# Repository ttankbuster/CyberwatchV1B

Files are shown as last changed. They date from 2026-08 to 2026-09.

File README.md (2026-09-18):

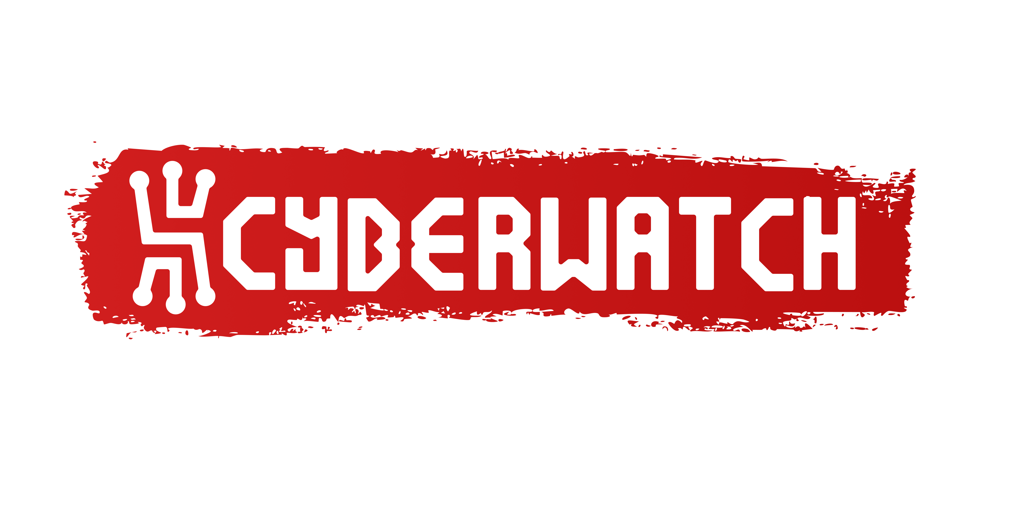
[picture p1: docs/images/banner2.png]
banner2
 
# CyberwatchV1B
The Cyberwatch is an extensible smartwatch built from scratch, targeting ESP32 hardware. It's current version is V1B.
Cyberwatch runs **Cyan**, a small operating system written in C with an embedded Lua runtime for app handling. Cyan is platform agnostic and can run on the watch and as a native desktop application, so the interface can be developed faster, without hardware in the loop by utilising [Clay](<https://github.com/nicbarker/clay>), a lightweight single header UI layout library. Apps are loaded at runtime from an SD card. 
Clay produces layout commands that are
consumed by either an ST7789V2 display handler on hardware or by SDL on a desktop machine. 
Cyan exposes hardware through a service architecture - a registry of
capabilities that apps and core tabs request as needed and can poll availability of arbitrarily. More info can be found with the [Word doc](<docs\Cyberwatch.docx>).

### Major Features
- Lua App Handling
- Watch-face
- Timer
- Stopwatch
- Remote Shell
- Settings

### Instillation
use `git clone --recurse-submodules https://github.com/ttankbuster/CyberwatchV1B.git` for installation, this git-repo uses submodules.

## Contents

## Functionality
| | |
| --- | --- |
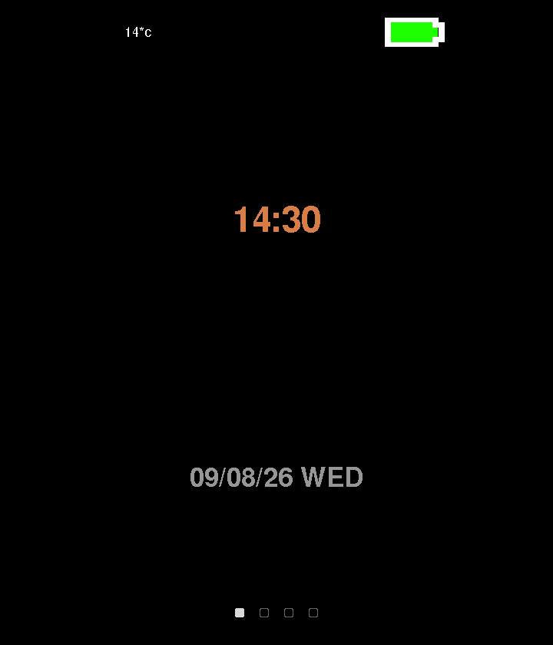
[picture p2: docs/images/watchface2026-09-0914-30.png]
Watch face
|  | **Watch face** - has digital and analogue variants. The analogue hands are drawn as quads on the same surface primitive used by apps. Shows the time, day of the week and date. |
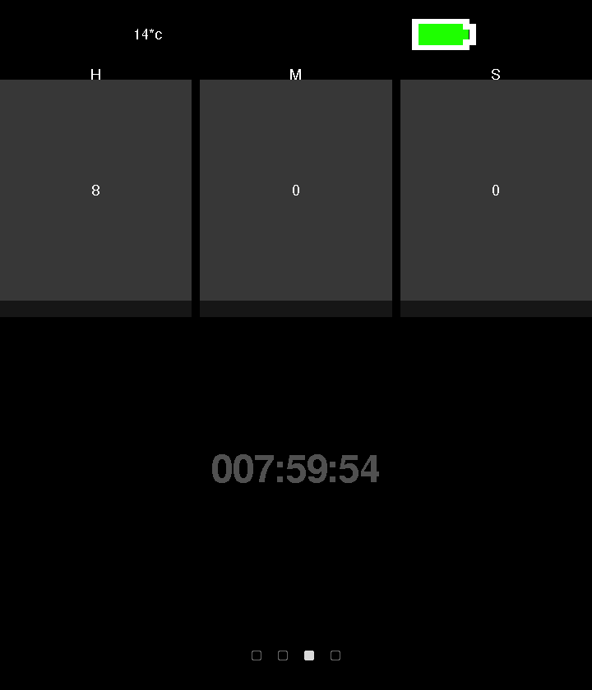
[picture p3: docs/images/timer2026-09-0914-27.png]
Timer
|  | **Timer** - three spin boxes for hours, minutes and seconds. Button 2 moves between fields, the crown adjusts the value, pressing the crown starts and pauses the timer. |
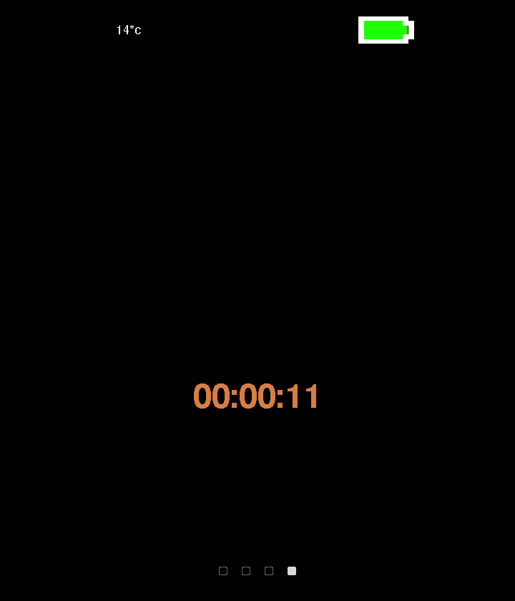
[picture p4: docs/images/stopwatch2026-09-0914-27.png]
Stopwatch
|   | **Stopwatch** - same interaction model, counting up rather than down. |
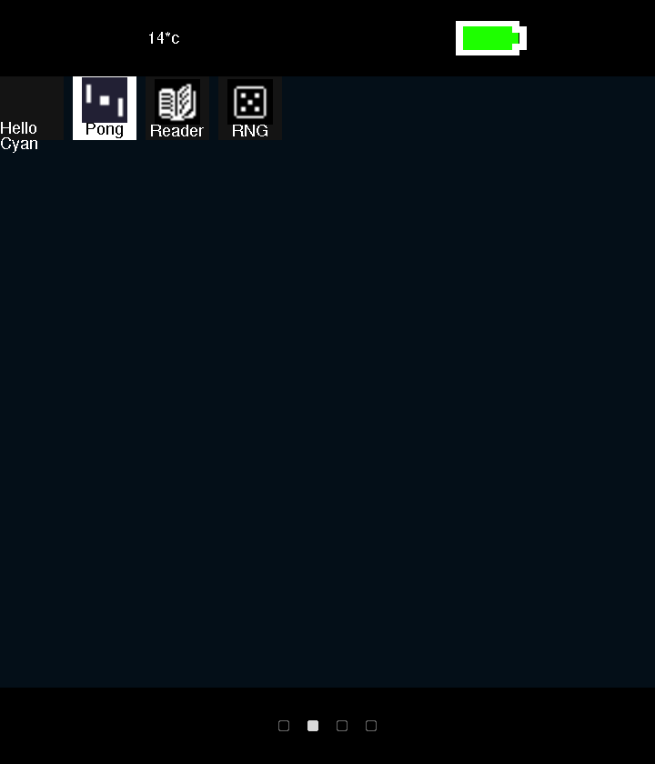
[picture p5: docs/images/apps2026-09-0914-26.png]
Catalogue
|  | **App catalogue** - displays a list of apps found on the SD card in rows and launches them. |
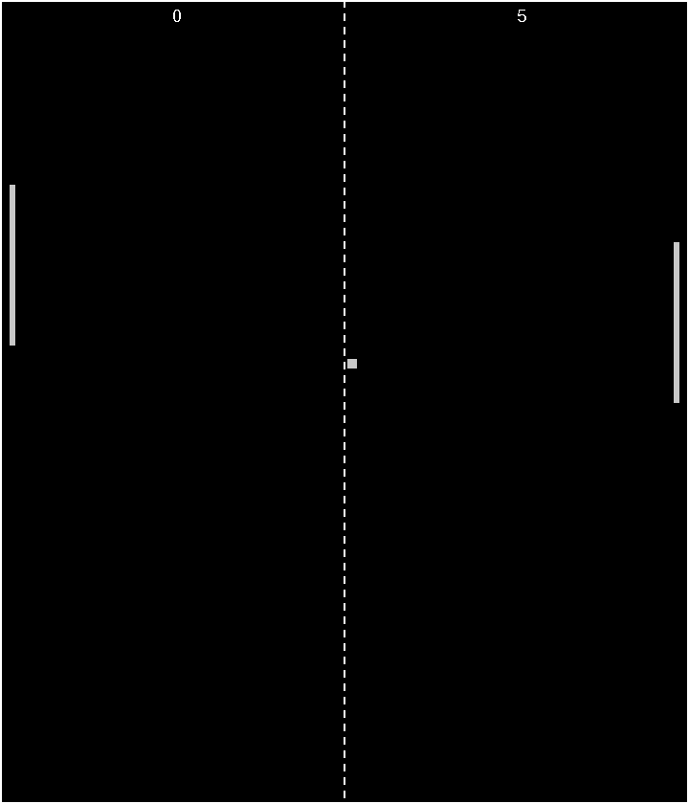
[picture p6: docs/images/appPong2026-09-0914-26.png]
Pong
|  | **Pong** - a demo app written entirely in Lua, using a bespoke app API. |
## Hardware
| | Function | Part | Interface | Notes |
| --- | --- | --- | --- | --- |
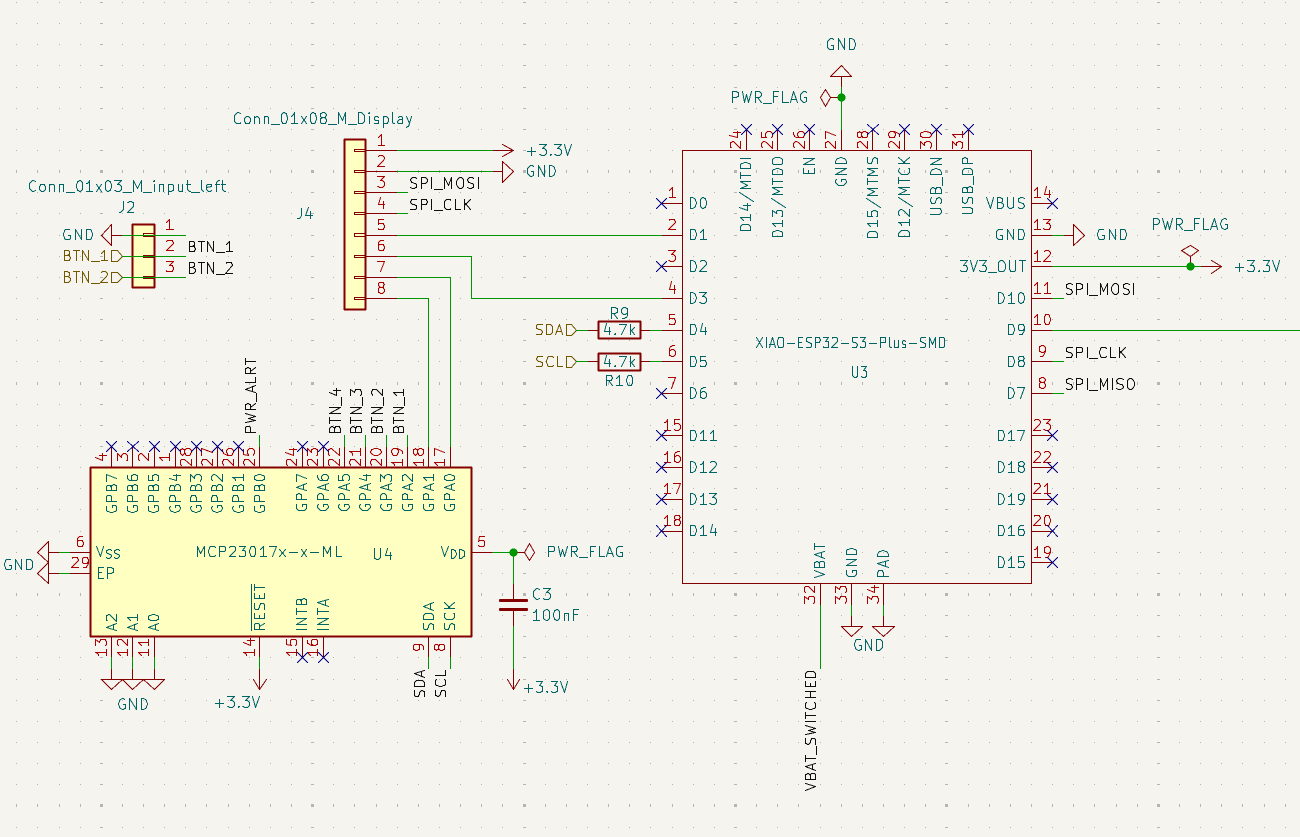
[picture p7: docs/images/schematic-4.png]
MCU
|  | MCU | Seeed XIAO ESP32-S3 Plus | --- | 240 MHz dual core, 8 MB PSRAM, 16 MB flash, WiFi + BLE 5.0, 14 µA deep sleep, integrated LiPo charging |
| Display  | Display | 1.69” LCD, ST7789V2 | SPI | - 240x280 pixel resolution<br>- 39x31.5mm |
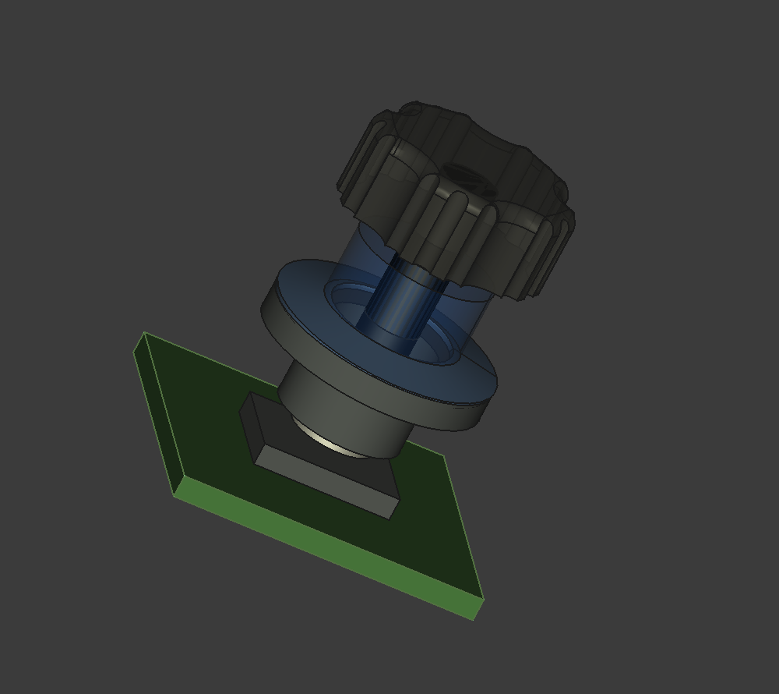
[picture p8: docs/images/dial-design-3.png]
Crown dial
|  | Crown dial | MT6701 magnetic encoder + dipole magnet. Annular Belleville popper for tactile feedback. | I2C | |
| GPIO expansion | GPIO expansion | MCP23017 | I2C | Frees ESP32 pins for the crown by moving the display RST and BL lines and the buttons onto the expander. |
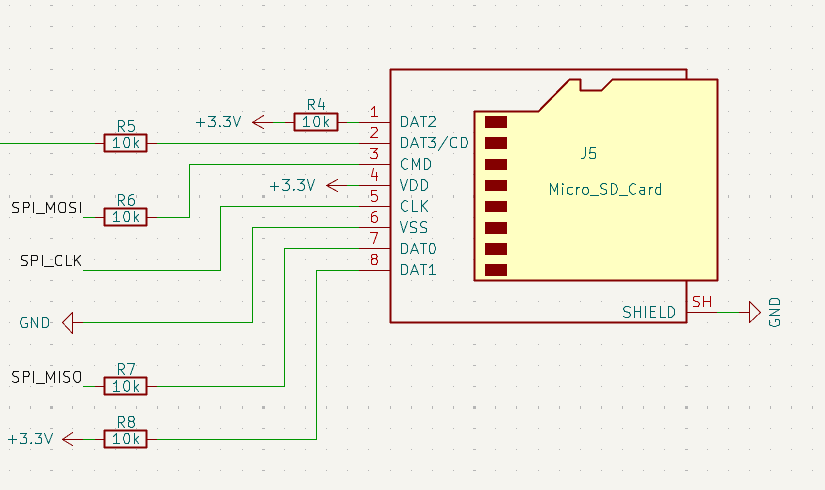
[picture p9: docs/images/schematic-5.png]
Storage
|  | Storage | MicroSD socket | SPI | 10 kΩ pull-ups on CS, MOSI, DAT1, DAT2 and MISO; <br>33 Ω series resistor on VCC to avoid the MCU browning out when the card is inserted |
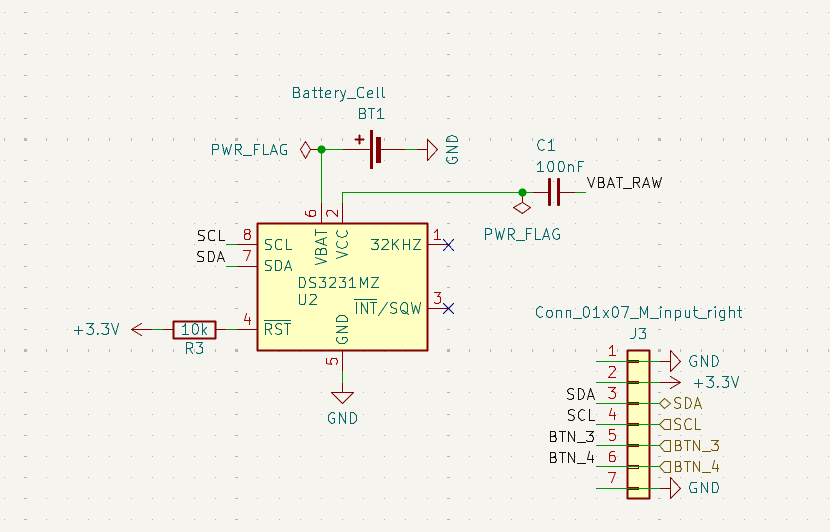
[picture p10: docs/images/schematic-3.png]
RTC
|  | Real-time clock & Temperature | DS3231MZ | I2C | Keeps time across power loss without a WiFi round trip.<br>Source of ambient temperature |
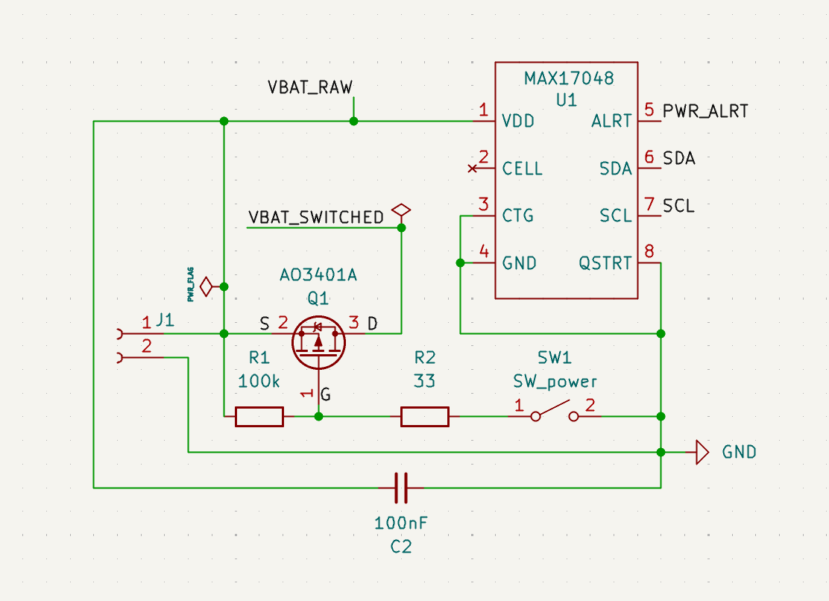
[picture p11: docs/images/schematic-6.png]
Battery gauge
|  | Battery gauge | MAX17048 | I2C | |
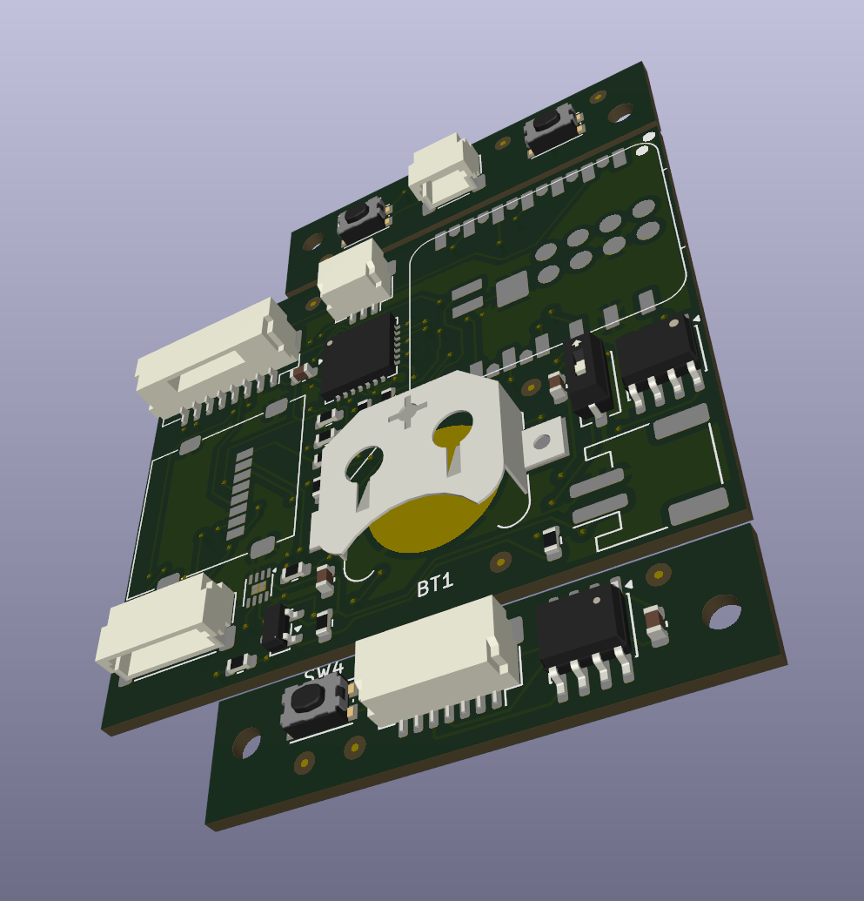
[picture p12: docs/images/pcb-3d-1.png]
Battery
|  | Battery | 3.7V 500mAh LiPo | --- | JST-PH Connector |
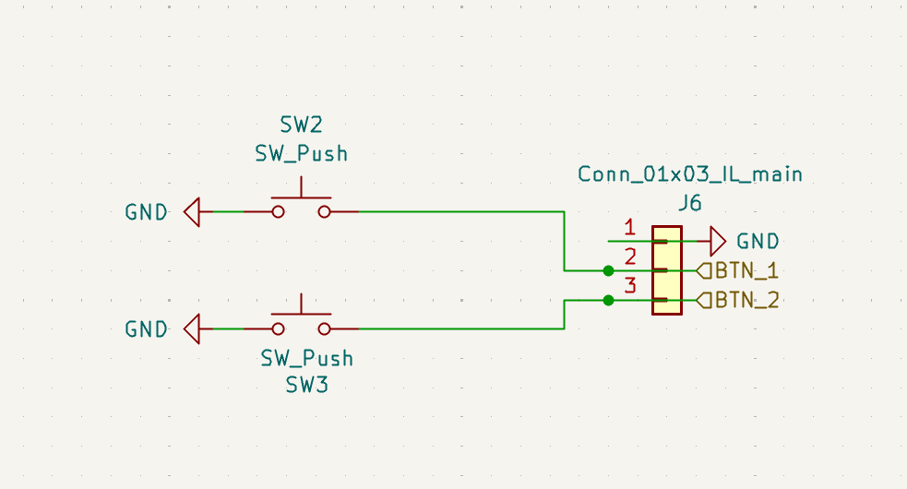
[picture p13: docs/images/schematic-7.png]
Buttons
|  | Buttons | 3x tactile switch | via MCP23017 | Buttons 1 and 2 on the left; button 4 and the crown on the right. |

## Software

The software follows a strict naming convention for all source code for the firmware and CyanOS to keep .

| For | Naming Convention |
| --- | --- |
| **types** | `PascalCase` |
| **fields** | `camelCase` |
| **functions** | `snake_case` |
| **constants** | `SCREAMING_SNAKE_CASE` |

`design/` holds the KiCad schematic and PCB, a FreeCAD case, component datasheets, and BOM spreadsheets for the hardware.

New public symbols should also take a `cyan_*` prefix. Styling is defined in `.clang-format` (stored at root).

Tests live under `test/`:
- `test/test_cyan_shell/` - Unity-style unit test for the shell command parser.
- `test/test_cyan_shell_repl/` - a Python-driven interactive REPL test, run via `pio test -e shell_repl`.

**PlatformIO Environments**

| Environment | Hardware Target | Notes |
| --- | --- | --- |
| `native` | Windows PC | uses SDL3 for window handling and rendering; this environment is used for development and iteration without hardware. |
| `esp32c3` | Seeed XIAO ESP32-C3 | earlier hardware target, watch-face tab only. |
| `esp32s3zero` | ESP32-S3 DevKitM-1 | full hardware target on a generic S3 dev board. |
| `xiao_esp32s3_plus`  | Seeed XIAO ESP32-S3 Plus  | full hardware target for the current CyberwatchV1B board. |
| `shell_repl` | Windows PC | dedicated env for interactively testing the shell command parser in isolation, run with `pio test -e shell_repl`. |

## Getting Started

Clone with submodules:
```
git clone --recurse-submodules https://github.com/ttankbuster/CyberwatchV1B.git
```
The repo vendors its dependencies (Clay, Lua, SDL3 + `_image`/`_ttf`, and two font families) as git submodules rather than package-manager dependencies, so `--recurse-submodules` is required - a plain clone leaves `external/` and the font folders empty.

To build and run the native simulator:
```
pio run -e native
build/native/program.exe
```
The native simulator has currently only been tested on Windows, where it should run out of the box with PlatformIO's toolchain and the SDL3 DLL installer written in python that checks for an instance of the SDL3 DLLs and coppies them into the executable directory if they are not found. This is to speed up starting on another machine. To target real hardware instead, swap `native` for one of the ESP32 environments above, e.g. `pio run -e xiao_esp32s3_plus -t upload`. This will flash to the ESP32-S3-Plus if it is connected with a usb-c cable, then start the operating system and serial monitor.

### Using the simulator

Launching the `native` build opens two windows: the watch display itself, and a separate console window for the interactive shell.

**Native CyanOS controls (`platform/pc/data_pc.c`)**

| Input | Maps to |
| --- | --- |
| Keys `1` / `2` / `3` / `4` | Buttons 1 / 2 / 3 / 4  |
| Mouse middle-click | Button 3 |
| Scroll wheel up/down | Crown dial up / down |
| up/down keys | Crown dial up / down |

**Shell commands (`cyan/console/cyan_shell.c`)**

| Command | Does |
| --- | --- |
| `help` | Lists all commands |
| `status` | Shows current Cyan status |
| `app list` / `launch <name>` / `exit` | Manage apps |
| `app permission add/remove/list <permission>` | Manage per-app permissions |
| `screenshot` | Saves a PNG of the current display to `screenshots/`, named by the active tab or running app plus a timestamp |
| `settings get/set/list <setting> [value]` | Read and write settings |

## Apps

Each app is a folder under `apps/` containing a `.cyan_app.lua` manifest plus its Lua script(s). Five example apps ship in the repo: `pong`, `reader`, `RNG`, `sodoku` and `hello_cyan`.

**Manifest fields (`.cyan_app.lua`)**

| Field | Meaning |
| --- | ---|
| `name` | Display name shown in the app catalogue |
| `script` | Entry-point Lua file, relative to the app's folder |
| `icon` | Icon bitmap shown in the catalogue |
| `dev` | If `true`, only loaded in debug builds |

Example (`apps/pong/.cyan_app.lua`):
```lua
return {
    name = "Pong",
    script = "pong.lua",
    icon = "icon.bmp",
    dev = false
}
```

Apps run sandboxed in their own Lua state and only see the API Cyan registers for them:
- `draw.rect(x, y, w, h, [r, g, b, a])` - filled rectangle
- `draw.text(x, y, text, [fontSize, r, g, b])` - text
- `draw.width()` / `draw.height()` - the app's drawable surface sizes
- `Event` - a table of input event constants (`Event.BUTTON1_DOWN`, `Event.SCROLL_UP`, etc.) for use in an app's event-handling code
- `print(...)` - routed into Cyan's own log output, tagged with the app's name

## Architecture

- **Service registry** (`cyan/data/services.h`) - a `ServiceRegistry` of `Service` entries (time, display, input, storage, power, apps, network, bluetooth, notifications, ...), each with `init`/`update`/`shutdown`/`available` functions and a criticality tier. Apps and core tabs can poll services at runtime.
- **Clay-based UI layer** (`cyan/clay_ui.c`) - an immediate-mode layout pass every frame, using [Clay](https://github.com/nicbarker/clay) to produce render commands consumed by a display backend.
- **`Surface` abstraction** (`cyan/data/surface.h`/`.c`) - a per-app pixel buffer that Lua apps draw into via the `draw` API, kept isolated from the OS's own rendering.
- **Platform backend split** - each platform implements its own `display_*` (rendering) and `data_*` (input/event) backends: `platform/pc/` (SDL3) and `platform/esp32/` (ST7789V2 over SPI via Arduino_GFX, MCP23017 I/O expansion).

The MCP23017 must finish initializing before the display's `RST` pulse, and the SD card's SPI setup must run after the display's own SPI init - reversing either hangs the board.

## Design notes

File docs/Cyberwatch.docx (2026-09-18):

# Cyberwatch V1B

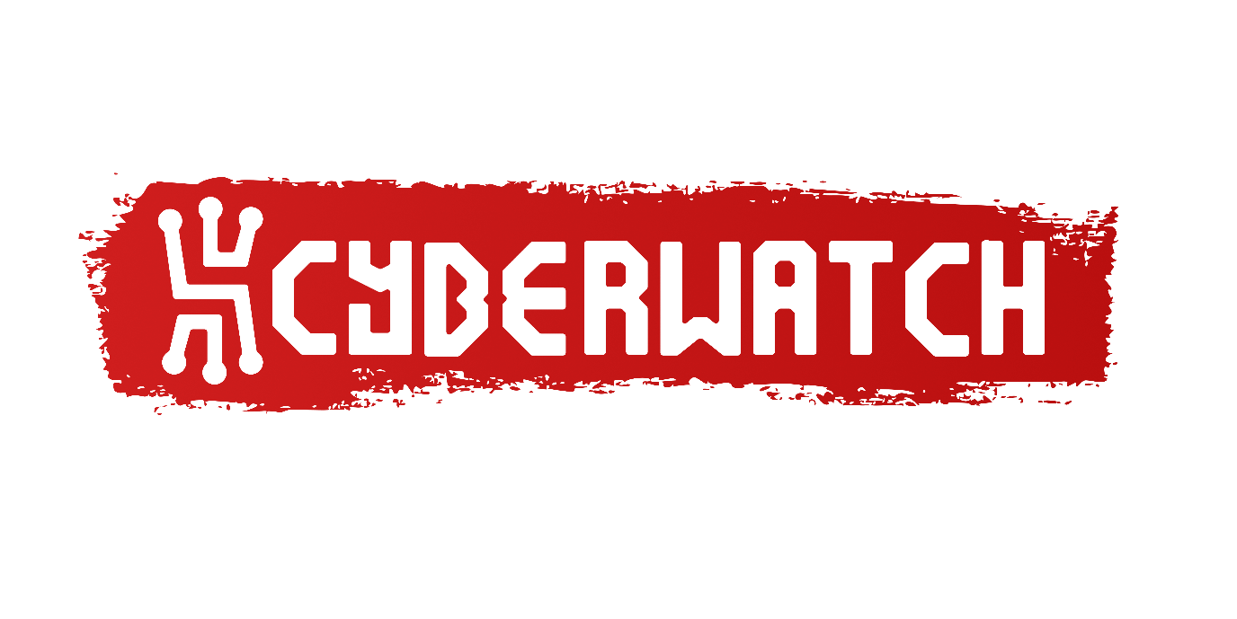
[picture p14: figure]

# 0.0 Introduction

Cyberwatch is a simple, versatile smartwatch with its own operating system called “Cyan”, for custom-made apps and tracking time. It is to a smartwatch what a “cyberdeck” is to a computer: open ended and reprogrammable.

A cyberdeck or cyber deck is a custom-built, portable personal computer, often one designed for a particular individualized purpose and usually with a cyberpunk (https://en.wikipedia.org/wiki/Cyberpunk) aesthetic.[1] (https://en.wikipedia.org/wiki/Cyberdeck) These devices are typically individually crafted, powered by laptop motherboards or single-board computers (https://en.wikipedia.org/wiki/Single-board_computer) (SBCs), such as Raspberry Pis (https://en.wikipedia.org/wiki/Raspberry_Pi), and include a display and keyboard

A coloured 1.69-inch LCD display shows the time, date and battery charge. The device is designed to operate for at least 24 hours on a single charge, and be recharged through a USB-C connection. A custom-built real time operating system called “Cyan” is responsible for managing hardware and the user interface. User interaction is facilitated by three physical buttons and a rotary crown, which can also be pressed as a button. The device measures x-mm by y-mm by z-mm. Cyberwatch began as an embedded systems project and a way to demonstrate my engineering ability. The longer-term ambition is more personal: to build a watch I genuinely want to wear, understand, repair and improve for as long as I am able. It is meant to work as a stand-alone device rather than an extension of a smartphone. It is not designed to track you or harvest your data. It is designed to be a useful tool, dependable and arguably more importantly: joyful.

Cyan is designed to target an ESP32 microcontroller, but is designed with platform abstraction in mind. This allows parts of the software to run on a PC for faster development and iteration, while the Cyberwatch hardware remains its primary platform for deployment.

## 0.1 Executive Summary

standalone one-page summary…

## 0.2 Index

# 1.0 Technical Overview

All requirements are assigned a reference number in the format of FR/NFR for Functional Requirement or Non Functional Requirement respectively, followed by a dash, then a category, then a number that is unique inside it’s given category.

Requirement Categories:

- A: User Interaction
- B: Display
- C: Application Handling
- D: System Management
- E: Platform Agnosticism

Change this to:

FR:

- A: Application Handling
- B: User Interaction
- C: System Management
- D: Display

NFR:

- P: Performance - rendering rate, input latency, response times
- W: Power & Endurance - battery life, charging, sleep current
- R: Reliability - graceful degradation, crash recovery, watchdog behaviour, app isolation
- M: Maintainability - platform abstraction, build separation, testability
- U: Usability - legibility at a glance, button feel, one-handed operation

## 1.1 Functional Requirements

Reference | Requirement Name | Description | Acceptance Criterion | Verification Method | Status
FR-A001 | Button Input | Cyberwatch shall accept input from three physical buttons.
FR-A002 | Rotary Input | Cyberwatch shall accept rotational input from the rotary crown.
FR-A003 | Crown Button | Cyberwatch shall detect presses of the rotary crown.
FR-B001 | Time Display | Cyberwatch shall display the current time.
FR-B002 | Date Display | Cyberwatch shall display the current date.
FR-B003 | Battery Status | Cyberwatch shall display the current battery charge level.
FR-B004 | Watch Face | Cyan shall provide a watch-face interface.
FR-B005 | Timer | Cyan shall provide a timer function.
FR-B006 | Stopwatch | Cyan shall provide a stopwatch function.
FR-C001 | Lua Applications | Cyan shall support applications written in Lua.
FR-C002 | Application Storage | Applications shall be stored on the hardware implementation’s SD card.
FR-C003 | Application Catalogue | Cyan shall provide an application catalogue from which installed applications can be selected.
FR-C004 | Application API | Cyan shall provide applications with access to supported display and input functionality.
FR-C005 | Application Manifest | Each application shall provide a manifest containing its required application information and services.
FR-D001 | Hardware Initialisation | Cyan shall initialise available hardware during system startup.
FR-D002 | Service Registration | Cyan shall identify available hardware capabilities and register the corresponding services.
FR-D003 | System Status | Cyan shall display the status of subsystems during startup.
FR-D004 | Reduced Capability Operation | Cyan shall continue operation with reduced capabilities when supported hardware or services are unavailable.
FR-E001 | PC Platform | Cyan shall be capable of operating on a PC platform for development and iteration.
FR-E002 | Platform Abstraction | Cyan shall separate platform-specific hardware implementations from platform-independent software functionality.

## 1.2 Non-Functional Requirements

…

## 1.3 System Architecture

layered model: hardware -> data/display -> service -> OS -> app

##Create a graphic here##

┌─────────────────────────────┐

│ Applications │ Lua, sandboxed, via App API

├─────────────────────────────┤

│ Cyan OS │ Shell UI, tabs, app lifecycle

├─────────────────────────────┤

│ Service Registry │ Time, Power, Input, Storage…

├─────────────────────────────┤

│ Hardware Abstraction │ Display, data, platform entry

├─────────────────────────────┤

│ Hardware │ ESP32-S3, ST7789, MCP23017…

└─────────────────────────────┘

Services are used to abstract across platform differences and provide a wrapper for the capabilities of the system which can be inspected during runtime. They may be only indirectly related to the underlying hardware, for example: notifications are purely a system capability, whereas storage may be unavailable if a component is missing or faulty – meaning .

Service | ID | Description | Criticality
Time | SERVICE_TIME | Provides current date and time from the platform RTC or system clock | HIGH
Power | SERVICE_POWER | Battery level, charge state, sleep and shutdown control | HIGH
Display | SERVICE_DISPLAY | Reports display dimensions to platform-independent code | HIGH
Input | SERVICE_INPUT | Polls physical buttons and rotary crown events | HIGH
Input Display | SERVICE_INPUT_DISPLAY | Pointer input for touchscreen or mouse | LOW
Storage | SERVICE_STORAGE | File read/write via the platform’s storage medium | HIGH
Network | SERVICE_NETWORK | WiFi connectivity and signal strength | MED
Bluetooth | SERVICE_BLUETOOTH | Bluetooth connection state | MED
Notifications | SERVICE_NOTIFICATIONS | Pending notification count from paired device | MED
Location | SERVICE_LOCATION | (reserved) | LOW
Audio | SERVICE_AUDIO | (reserved) | LOW
Vibration | SERVICE_VIBRATION | (reserved) | LOW

# 2.0 Hardware Design

…

## 2.1 Power System

…

## 2.2 Electronic Components

…

## 2.3 PCB Design

…

## 2.4 Structural Design

Enclosure/case etc…

2.5 Mechanical Design
- dial: bearing, magnet, tolerances

# 3.0 Software Design

…

## 3.1 Cyan

Cyan is the home-brewed operating system, custom built for the Cyberwatch hardware. On startup, Cyan will display a splash-screen and exhibit the Cyan logo.

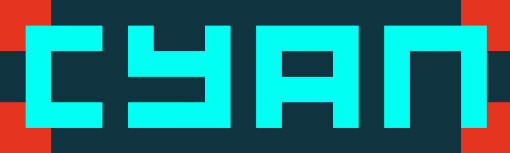
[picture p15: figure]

It will then load hardware capabilities and register services, checking the health of each system step by step. Cyan is designed to run with reduced capabilities, meaning it is robust against failure when hardware does not meet full expectations (see §1.3 System Architecture for details on Service handling). Displaying each sub-system’s status during boot. Once startup is complete, the user is taken to the watch-face - the first of four tabs Cyan provides: (1) Watch-face, (2) App Catalogue, (3) Timer, (4) Stopwatch. (elaborated on in §3.2 User Interface).

## 3.2 User Interface

A crucial library chosen for Cyan is Nic Barker’s Clay. A lightweight real time, and importantly, platform agnostic layout engine. The UI is first laid out using Clay and is then passed on to the renderer - which is implementation specific. During native targeting the rendering engine used is SDL3, whereas Arduino GFX supports hardware on the ESP32. The user interface is recalculated each updated, meaning it is event driven. This works well with Clay’s immediate mode architecture as recalculating the entire layout from scratch is very simple, but this can be slightly more intensive than persistent UI elements allowing the rendering loop to skip a portion of the screen altogether. Fortunately, immediate mode UIs also have the added benefit of robustness: because everything is recalculated from scratch each time, there are no miscalculations that can survive across frames. After layout calculations are complete, the list of render commands is interpreted by either the SDL3 Clay backend or a custom-built receptacle for ArduinoGFX, converting layout commands into draw commands.

Sometimes for avoiding complexity, Clay is bypassed as the primary mode of display-management. For example: during app execution…

### 3.2.1 Cyan Watch-Face Tab

The watch-face is a simple UI for showing the current time in a format of the user’s choice, stored as setting #xthe day of the week and current date, also configurable using settings #y and #z respectively.

This is achieved by storing a time object and character buffers which are written to each update.

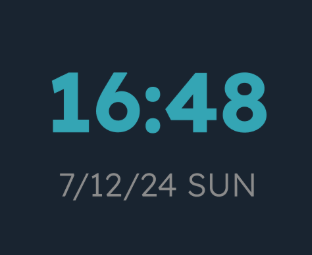
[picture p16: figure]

Allowing Cyan to retrieve the date and time from the current platform and produce a string which is then displayed on screen using Clay’s in-built String object.

### 3.2.2 Cyan App Catalogue Tab

…

### 3.2.3 Cyan Timer Tab

…

### 3.2.4 Cyan Stopwatch Tab

…

## 3.3 Application System

Cyan provides support for applications written in Lua. These applications, on the hardware implementation, are stored on the SD card, inside of the root folder “apps/”. Each app has its own folder, containing a Lua script, a thumbnail image and a manifest file also written in Lua – this allows for a simpler implementation than writing an additional interpreter for a JSON manifest. During startup, Cyan scans through all subdirectories inside of the apps/ folder and spins up a temporary Lua instance to read manifest files into an app object, storing information such as the name of the app, the file address to the app thumbnail and the services the app will require (e.g. WiFi).

Once an app has been selected to launch from the app catalogue, a new Lua instance is created to interpret the app’s script in real time. To exit an application, the user can press button one.

An API is exposed to the application, allowing draw calls and input events to be transacted between the operating system and a running application. All visuals produced by the application are rendered to a surface target abstraction, allowing the app to display inside of the pre-existing UI by converting the in-app coordinates to global screen coordinates after the layout step is completed.

API Draw Calls
Name | In App Signature | Backend Signature | Effect
Draw Rectangle | draw.rect (x, y, w, h, r, g, b) | AppHandler _draw_rect (lua_State *L) | Draws a rectangle using specified quad and colour.
Draw Text | draw.text (x, y, text, font_size, r, g, b) | AppHandler_draw_text (lua_State *L) | Prints text on screen at the given coordinate
Draw Width | | AppHandler _draw_rect (lua_State *L)
Draw Height

## 3.4 Hardware Abstraction

…

## 3.5 PC Platform

SDL etc

## 3.6 Settings & Configuration

- standalone, no Lua dependency

## 3.7 Remote Shell

- serial now, WiFi later

# 4.0 Testing and Verification

retrospective: hardware bring-up discipline

prospective: planned Unity tests

# 5.0 Development History

…

## 5.1 Hardware Decisions

MCU

- ESP32-S3 over C3 for primary target; C3 kept as reduced-capability build
- XIAO ESP32-S3 Plus over base S3 and Waveshare S3-Zero
- module, not bare IC (V1) - isolates RF risk to V2

DISPLAY

- Waveshare 1.69" ST7789V2, 240x280 SPI
- JST GH 1.25mm 8-pin - custom symbol built, no Plus-specific footprint found

I/O EXPANSION

- MCP23017 for I2C GPIO (buttons + display RST/BL)
- SOIC (-SO) over QFN (-ML) - hand-solderability

RTC

- DS3231 family - free built-in temp sensor
- DS3231MZ (SOIC-8) over DS3231M (SOIC-16) - same specs, smaller
- RV-3028-C7 rejected for V1 (leadless) - deferred to V2
- CR1220 over CR2032 - smaller, shorter but replaceable backup life
- no trickle-charge circuit - real fire-risk finding, deliberately omitted

ROTARY INPUT

- AS5600 (Hall-effect I2C) over mechanical encoder - sealed, contactless
- SOIC-8 footprint verified against real datasheet dims
- footprint sourced from KiCad's own library, not unverified SnapEDA
- MLX92213 rejected - wrong sensor category (binary latch, not angle)
- ADA4570BRZ rejected - needs external ADC, wrong complexity for use case
- bearing material - still open, deferred to empirical test

STORAGE

- bare microSD socket, not breakout module
- SPI mode over SDIO - fewer pins
- SCK/MOSI shared with display bus, each device own CS

POWER

- AO3401 P-MOSFET for isolation - raw switch undersized for WiFi burst current
- MAX17048 fuel gauge - simple, proven, official Espressif driver (MAX17055 deferred to V2 - more accurate, more complex)
- JST-PH 2.0mm 2-pin for main battery

PASSIVES

- I2C pull-ups: 4.7k, per AS5600 datasheet
- SD pull-ups: 10k, per Espressif ESP-IDF docs

## 5.2 Software Decisions

…

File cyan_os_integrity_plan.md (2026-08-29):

# Cyan OS Integrity Initiative — Stepped Plan

*Formalized plan for hardening Cyan OS: fault tolerance, service criticality,
a native settings system, power-aware rendering, and a remote shell — bounded
by a full audit on each end.*

---

## Cross-cutting rule, applies to every phase below

**Each phase ends with a full boot-and-smoke-test on real hardware before
the next phase begins, followed by a git tag at that known-good point.**
This project has already hit the same regression twice (`tabCount`
initialization silently disappearing during unrelated edits, reintroducing
a crash that was already fixed once). An 8-plus-phase restructuring effort
touching core architecture is exactly the environment that happens in
again, quietly, several phases deep, with no easy way to know which phase
introduced it. This rule is non-negotiable, not a nice-to-have.

---

## Current status (updated as work progresses)

- **Phase 1 closed, tagged `phase1-pc-verified`.** **Phase 2 (criticality
  model) started** — data model landed (`CyanCriticality` enum, the two
  `Service` fields, static tiers for the two currently-registered
  services), full detail under Phase 2 below.
- **Phase 0, audit pass complete, both confirmed bugs now fixed in the
  working tree.** Originally decided to keep Phase 0 audit-only and defer
  both bugs (the `app_handler.c` buffer overflow and the
  `display_st7789.cpp` out-of-bounds read) to Phase 1 alongside the
  rename — superseded: fixed directly instead, each as its own isolated
  change (see Audit Findings Log for the diffs). **Committed** as
  `de4f58a` ("memory safety fix"), which also included the
  `main_esp32.cpp` dead-code cleanup and this plan doc itself.
  **PC half of the boot-and-smoke-test complete**: native build compiles
  clean and the launched binary stays up and responsive (window "Watch",
  no crash) — confirms the `app_handler.c` fix. Tagged at that point:
  `phase0-pc-verified` → `de4f58a`. **Still outstanding**: the ESP32
  hardware boot test for the `display_st7789.cpp` icon-dimension fix,
  which is ESP32-only and unverifiable on the PC build. Phase 0 isn't
  fully closed until that runs too.
  - **Follow-up commit landed outside this documented flow**: `8e53165`
    ("memory safety fix #2") added three more `app_handler.c`/`.h` changes
    on top of `de4f58a` — see Audit Findings Log for detail on each.
    Reconciled here since it wasn't logged when made, matching the
    cross-cutting rule's concern about silent drift between phases.
    PC boot-and-smoke-test re-run against this commit specifically
    (native build clean, binary stayed alive and responsive, indexed all
    5 apps correctly, no crash) — tagged `phase0-pc-verified-2` →
    `8e53165`. ESP32 hardware boot test is still the one outstanding item
    blocking Phase 0 closure — unverifiable from this environment,
    needs to be run on real hardware.
  - **Explicit decision, 2026-08-16**: no ESP32 hardware access right
    now. Rather than stall, proceeding into Phase 1 with Phase 0 held
    open specifically on that one item — the PC-verifiable half (the
    `app_handler.c` overflow, and everything else audited off the
    source directly) is done and tagged. The ESP32 boot test for the
    `display_st7789.cpp` icon fix will be run once hardware is
    available again; this is a deliberate, logged exception to the
    cross-cutting rule's "boot-test before the next phase" ordering,
    not a silent skip.
  - `src/` reconciliation: **resolved** — confirmed directly against the
    repo tree that no `src/` directory exists; nothing to migrate.
  - Entry points audited (`main_pc.c`, `main_esp32.cpp`) — see Audit
    Findings Log below.
  - `cyan_os.c`/`cyan_os.h` audit: **unblocked and complete** — read
    directly off disk (`cyan/cyan_os.c`, `cyan/cyan_os.h`) once working
    from Claude Code, which has direct filesystem access; the prior
    attachment-delivery issue doesn't apply in this environment. Audit
    expanded outward from there to everything `cyan_os.c` pulls in
    directly: `app_handler.c/h`, `surface.c/h`, `services.h`,
    `services_base.c`, and both platform backends
    (`data_pc.c`/`display_sdl.c`, `data_esp32.cpp`/`display_st7789.cpp`) —
    see Audit Findings Log below. Two concrete, reproducible bugs found
    (buffer overflow, out-of-bounds read); both deferred to Phase 1, see
    decision above.
- **Decision made, deferred**: `CyberwatchData` → `CyanData` rename,
  agreed but intentionally not executed until Phase 1 (naming pass), so
  it happens as one deliberate sweep rather than piecemeal. Scope
  confirmed during this pass: touches `cyan_os.c`, `cyan_os.h`, `data.h`,
  `app_handler.h`, `services.h`, and every platform data file — matches
  what Phase 1 already expected, no surprises. **Done** — landed in
  `6d60554`.
- **Gap reconciled, 2026-08-29**: this status section hadn't been updated
  since `6d60554`, but 8 more commits had landed since (mostly unrelated
  hardware/case-design/documentation work — `485a9d7`, `b2f2483`,
  `c793bb0`'s electronics portion, and the schematic/analogue commits
  through `9153969`). One of those, **`c793bb0`, silently renamed every
  `app_handler_*` function to `AppHandler_*`** (PascalCase) without being
  logged anywhere — exactly the undocumented-drift scenario the
  cross-cutting rule exists to catch, since every other module
  (`services_*`, `surface_*`, `display_*`, `cyan_*`) stayed snake_case.
  Latest commit (`0ef6e52`, "added code style enforcement") also added
  `.clang-format` plus two **empty** stub files, `cyan/cyan_shell.c` and
  `cyan/cyan_shell.h` — read as early Phase 3 scaffolding, but Phase 2
  (criticality model) hasn't been started yet (confirmed: `services.h`
  has no `CyanCriticality` enum or `staticCriticality`/`dynamicCriticality`
  fields). **Explicit decision**: revert the `AppHandler_*` drift back to
  `app_handler_*`, finish Phase 1's two still-outstanding dead-code items
  before moving on, and leave the `cyan_shell.c/h` stubs untouched for
  now — Phase 2 comes next, per the plan's own sequencing.
  - Reverted in the working tree: `app_handler_init`, `app_handler_launch`,
    `app_handler_unload`, `app_handler_run_frame` (was renamed
    `AppHandler_update`), `app_handler_dispatch_events`,
    `app_handler_shutdown`, `app_handler_index`, `app_handler_print`, and
    the four Lua draw closures (`app_handler_draw_rect/width/height/text`,
    previously `lua_draw_*` before `c793bb0`, then `AppHandler_draw_*`) —
    all back to snake_case, across `app_handler.c`, `app_handler.h`, and
    every call site in `cyan_os.c`. See Audit Findings Log for detail.
  - Both remaining Phase 1 dead-code items (see Audit Findings Log,
    original entries) are now resolved: `cyan/data/timer_handling.c`
    deleted (empty, vestigial), `display_load_image()` in
    `display_st7789.cpp` deleted (dead, zero call sites, confirmed again
    before removal).
  - PC boot-and-smoke-test re-run against this working tree: native build
    clean, binary launched, stayed alive and responsive for 5+ seconds
    with no crash or error output, terminated cleanly. Tagged
    `phase1-pc-verified` once committed.
  - **New finding, not fixed this pass**: `cyan/tabs/screen_app.c` and
    `screen_catalogue.c` have their own pre-existing mixed-case names —
    `clay_AppHandler_app`, `clay_AppHandler_catalogue`,
    `render_AppHandler_catalogue`, `AppHandler_catalogue_move` — embedding
    `AppHandler` PascalCase inside otherwise snake_case names. These
    predate `c793bb0` (unrelated to that drift) and predate this plan's
    Phase 0 audit entirely. Left as-is — out of scope for this specific
    drift-revert — but logged as a Phase 1 naming-sweep candidate.

---

## Audit Findings Log

*Running log, appended to as each file is reviewed — not just Phase 0's
findings, every phase that touches existing code adds here.*

### `platform/pc/main_pc.c`, `platform/esp32/main_esp32.cpp`

| Finding | Severity | Disposition |
|---|---|---|
| ESP32 `loop()`'s `bool running` is declared fresh every call, value never meaningfully consulted afterward | Informational | **Accepted, known pattern** — ESP32's `loop()` has no real "exit" concept regardless. Recorded so a future reader doesn't mistake this for an oversight |
| Commented-out dead code (`// while(1)delay(1000);`) in `setup()` | Trivial | Cleanup item — sweep in Phase 1 |
| `main_pc.c` uses `clock()` for `dt` — measures CPU time, not strictly wall-clock; can diverge under some schedulers | Informational | Recorded as a known characteristic, matches original project convention — not changed unless later deliberately decided otherwise |
| Neither entry point has bounded-time protection around `esp32_hardware_init()`/`cyan_init()` failure — both halt forever or return an error | Expected, pre-Phase-4 | **Not a new finding** — this is exactly what Phase 4's bounded-time-init work replaces |

### `cyan/cyan_os.c`, `cyan/cyan_os.h`, and everything they directly pull in (`app_handler.c/h`, `surface.c/h`, `services.h`, `services_base.c`, `data_pc.c`/`display_sdl.c`, `data_esp32.cpp`/`display_st7789.cpp`)

| Finding | Severity | Disposition |
|---|---|---|
| `app_handler.c:184-185` (`app_handler_index`) — `snprintf(app.name, MAX_FILE_PATH, ...)` and `snprintf(app.path, MAX_FILE_PATH, ...)` passed `MAX_FILE_PATH` (256) as the size bound, but `app.name`/`app.path` are each `char[MAX_FILE_NAME]` (64 bytes) per the `AppEntry` struct (`app_handler.h:18-19`). For `app.path`, the written content is `"<path>/<foldername>"` — not bounded to ≤63 chars the way `folders.names[i]` alone is — so a folder name of roughly 60+ characters overflowed past `path`'s 64-byte field into the adjacent `icon` field. `app.name`'s copy was currently masked (safe only because `scan_folder` truncates source names to ≤63 chars first), but the size argument itself was still wrong. | **Bug — reachable stack buffer overflow** | **Fixed** — originally logged as deferred to Phase 1, but fixed immediately instead once flagged: both calls now use `sizeof(app.name)` / `sizeof(app.path)`. Still needs the boot-and-smoke-test before this is considered closed |
| `display_st7789.cpp:109` and `:114` — `convertRgb888ToRgb565(ICON_EMPTY_TAB, ICON_BATTERY_WIDTH, ICON_BATTERY_HEIGHT)` and the equivalent for `ICON_FULL_TAB` passed the **battery** icon's dimensions instead of their own. Confirmed against the actual asset headers: `ICON_BATTERY` is 30×18 (540px), `ICON_EMPTY_TAB`/`ICON_FULL_TAB` are each 12×12 (144px) — so this read ~396 pixels (1.5KB) past the end of a 144-pixel static array on every boot, and also left `iconEmptyTab.pixels`/`iconFullTab.pixels` populated with the wrong stride relative to `width`/`height` — garbled tab icons, independent of the OOB read. PC's `display_sdl.c:55-62` never had this bug. | **Bug — confirmed out-of-bounds read + wrong render** | **Fixed** — originally logged as deferred to Phase 1, but fixed immediately instead once flagged: both calls now use each icon's own `ICON_EMPTY_TAB_WIDTH/HEIGHT` / `ICON_FULL_TAB_WIDTH/HEIGHT` constants. ESP32-only change — needs the boot-and-smoke-test on real hardware before this is considered closed (can't be verified on the PC build) |
| `IconHandle`/`imageHandle` pattern — explicit audit target from the Phase 0 scope below | N/A | **Checked, consistent — no bug.** It's a deliberately opaque, per-platform `void*`: PC (`data_pc.c`/`display_sdl.c`) always writes/reads it as `SDL_Texture*`; ESP32 (`data_esp32.cpp`/`display_st7789.cpp`) always writes/reads it as `IconHandle*`. Platform-agnostic code (`screen_catalogue.c:72`) only passes it through to `display_draw_image`, never dereferences it directly. No cross-platform mixing found. |
| `cyan/data/timer_handling.c` is an empty file, despite its name implying it holds `timer_init`/`timer_cycle_element`/`timer_toggle`/`timer_spinbox_input` (declared in `data.h`). Traced and resolved: those are actually implemented in `cyan/tabs/screen_timer.c`, and `stopwatch_toggle`/`stopwatch_reset` in `cyan/tabs/screen_stopwatch.c`. | Trivial | **Not a missing-implementation bug** — vestigial/misleadingly-named empty file. **Deleted**, 2026-08-29 |
| `display_load_image()` in `display_st7789.cpp:166` is defined but has no call sites anywhere in the codebase and isn't declared in `display.h`. | Trivial | Dead code — **deleted**, 2026-08-29, re-confirmed zero call sites first |
| `app_handling/app_handler.c`, all six public functions (`app_handler_init/launch/unload/run_frame/dispatch_events/shutdown`) plus internal `app_handler_index` and the Lua-facing statics, were silently renamed to `AppHandler_*` (PascalCase) in `c793bb0`, undocumented at the time. | **Undocumented drift, matches the cross-cutting rule's exact concern** | **Reverted to snake_case**, 2026-08-29, per explicit decision — see Current status above for full list and reasoning |
| `cyan_os.h`'s include guard is `CYBERWATCH_H` (`cyan_os.h:2-3`) — leftover from the pre-rename name. Extends the Phase 1 naming-drift note (which already covers function naming) to include guards specifically. | Informational | Folds into the already-deferred `CyberwatchData` → `CyanData` sweep in Phase 1, not a new decision |
| Input debounce — confirmed at its exact location: `data_esp32.cpp:43-63` (`pollButtons`) does pure edge detection (`pressed != lastButtonNPressed`), no time-based debounce anywhere in the poll path. | Confirmed, matches Phase 0 scope | Not a new finding — this is the debounce gap the plan already named as an explicit audit target (see below); recorded here with its concrete file/line now that the file has been read directly |
| `app_handler.c:186` (`app_handler_index`, landed in `8e53165`) — even after the `sizeof(app.path)` fix, `snprintf` silently truncates rather than erroring when `"<path>/<foldername>"` still doesn't fit `app.path`'s 64 bytes. A truncated path is a distinct hazard from the original overflow: it's a valid-looking path to the *wrong* location (or a nonexistent one), which fails later, further from the actual cause. | Hardening, not a new memory-safety bug (the overflow itself was already fixed) | **Fixed** — `snprintf`'s return value is now checked; a folder name that would overflow `app.path` is logged and the entry is skipped instead of silently truncated. Covered by this pass's PC boot-and-smoke-test (`phase0-pc-verified-2`) |
| `app_handler.c:266` (`app_handler_run_frame`, landed in `8e53165`) — no null check on `AppHandler->appLua` before dereferencing it via `lua_getglobal`. Traced every call site (`cyan_os.c:117-189`): all four `data.state` writes (`launch_app`, `exit_app`, init, shutdown) update `state` and `appLua` together, synchronously, single-threaded — so a null-`appLua` call during `CYW_APP_RUNNING` isn't reachable through any currently-existing control path. | Defensive hardening, not a demonstrated live bug under current control flow | **Fixed** — added as a guard anyway (cheap, and Phase 6's capability-enforcement/Lua-bounds work will add more control paths here where this stops being trivially true). Worth re-checking reachability once Phase 6 lands |
| `app_handler.h` — `app_handler_count`, `app_handler_name`, `app_handler_icon`, `app_handler_is_running` were declared but never defined or called anywhere in `cyan/`. | Trivial | **Removed** in `8e53165`, ahead of the general Phase 1 dead-code sweep — confirmed zero remaining references before deletion |
| `platform_resolve_path()` — declared in `data.h`, defined separately on both `data_pc.c` (SDL_malloc-backed) and `data_esp32.cpp` (malloc-backed) — zero call sites anywhere in the codebase on either platform. Distinct from `platform_store_resolved_path()` (the caller-supplies-the-buffer variant), which *is* used everywhere and stays. | Trivial | Dead code, both platforms — **deleted**, 2026-08-29, from `data.h` and both platform `.c` files. PC build/boot-tested; ESP32 side is a pure deletion of an unreferenced function, same risk profile as the PC-verified half |

### `data_esp32.cpp` / `data_pc.c` vs. the services registry — architectural finding, 2026-08-29

Read `data_esp32.cpp` in full while starting Phase 2. **The services
registry that Phase 2's criticality model sits on top of is bypassed
entirely by every real subsystem except Time and Power, on both
platforms.** Concretely: ESP32's `pollButtons`/`pollEncoder` (Input),
`readRTC` (Time — note ESP32 doesn't even register a `TimeService`,
unlike PC), and `scan_folder`/`load_image` (Storage) are all called
directly from `update_data()`/`app_handler.c`, never through a
registered `InputService`/`StorageService`. PC's `data_pc.c` has the
identical shape: `scan_folder`/`load_image` (Storage) and display's own
event polling (Input) are wired directly, not through the registry.
`register_available_services` on ESP32 (`data_esp32.cpp:311-313`) is a
no-op that only logs. **This means `services_is_available()` would
report `Input`/`Storage`/`Display`/`Notifications` as unavailable on
both platforms today, even though Input and Storage plainly work** —
the registry just was never told about them.

This isn't a bug in what exists — everything that's wired directly
still functions correctly. It's a **gap between the architecture the
plan's later phases assume and what's actually built**: Phase 5
("periodic re-registration / availability re-check for every service")
and Phase 4's boot-ordering work both presuppose the registry is the
real source of truth for every subsystem, which isn't true yet. Left
unflagged, Phase 4/5 would either silently build on a registry that's
missing most of the OS, or rediscover this same gap mid-phase.

**Not fixed this pass** — deliberately. Registering Input/Storage/
Display/Notifications as real services means restructuring the main
update loop on both platforms, which is a materially bigger and riskier
change than this pass's scope (dead-code cleanup + a data-model addition).
Recorded here as a decision point for whichever phase migrates these —
most naturally Phase 2's own completion (finish what it started) or as
explicit prep work at the top of Phase 4, before boot-ordering logic
starts relying on registry state that isn't there yet.

**Before changing anything.**

- **Reconcile the actual current file tree against what's been assumed in
  prior planning.** Confirmed via direct repo check: `src/` still exists
  as a top-level folder alongside `cyan/`, contradicting the last project
  status summary's description of a full migration. Resolve this first —
  know what you're actually starting from.
- First audit pass, specifically for:
  - Memory safety (null-pointer risk, buffer bounds, the `IconHandle`
    pattern's consistent application across every image-loading path).
  - Logic errors.
  - **Input debounce** — confirmed absent. Current edge detection
    (`pressed != lastPressed`) has no time-based debounce at all; real
    mechanical switch bounce can register multiple spurious events within
    milliseconds. Named explicitly as an audit target, not left implicit.
- Output: a concrete, written list of findings — this becomes the
  baseline the Phase 9 final audit is measured against.

---

## Phase 1 — Naming & casing standardization

Mechanical, done early and deliberately so every subsequent phase is
written correctly the first time.

- Confirm and formalize the existing convention (already consistently
  followed): `PascalCase` types, `camelCase` fields, `snake_case`
  functions, `SCREAMING_SNAKE_CASE` enum values/macros.
- New rule going forward: every new public symbol not already covered by
  an established sub-prefix (`display_*`, `app_handler_*`, `services_*`)
  gets `cyan_*`.
- Sweep existing inconsistencies introduced during the earlier Cyan OS
  reframe (drifted top-level function naming around the `cyan_os_*` /
  bare-name transition).
- **`CyberwatchData` → `CyanData` rename** — agreed during Phase 0,
  executed here as one deliberate sweep rather than piecemeal. Touches
  every file with a `data->` access, so this should be done as its own
  isolated commit, boot-tested on its own before anything else in this
  phase proceeds on top of it.
- ~~Two bugs carried in from the Phase 0 audit, deferred here rather than
  fixed piecemeal~~ — superseded, fixed directly during Phase 0 instead
  once flagged (see Audit Findings Log): the `app_handler.c:184-185`
  buffer-size mismatch and the `display_st7789.cpp:109/114` tab-icon
  dimension mixup. Nothing left for Phase 1 to carry on these two.
- **Dead-code sweep, done 2026-08-29**: `cyan/data/timer_handling.c`
  (empty, vestigial) and `display_st7789.cpp`'s dead `display_load_image()`
  both removed. The `main_esp32.cpp` commented-out dead code was already
  removed earlier (part of `de4f58a`).
- **Undocumented `AppHandler_*` naming drift, found and reverted
  2026-08-29** — see Current status and Audit Findings Log for detail.
  Function naming across `cyan/` is snake_case-consistent again as of
  this pass.
- **Still open, deliberately not touched this pass**: `screen_app.c`'s
  `clay_AppHandler_app` and `screen_catalogue.c`'s
  `clay_AppHandler_catalogue` / `render_AppHandler_catalogue` /
  `AppHandler_catalogue_move` mix `AppHandler` PascalCase into otherwise
  snake_case names. Pre-existing, predates this plan's Phase 0 audit —
  a real Phase 1 naming-sweep candidate, not yet actioned.

---

## Phase 2 — Criticality model

Foundational — Phases 4–7 all consume this.

**Started 2026-08-29, data model landed; started right after Phase 1's
close (`phase1-pc-verified`) per the explicit decision to finish Phase 1
first.**

- New type: `CyanCriticality` enum. **Done** — `services.h`, four values
  (`CRITICALITY_LOW/MED/HIGH/FOUNDATIONAL`).
- `Service` struct gains two fields: `staticCriticality` and
  `dynamicCriticality` — one enum, two variables per service, as specified.
  **Done**. `services_register()` seeds `dynamicCriticality` to match
  `staticCriticality` at registration time, since no app can be running
  yet at that point — matches the "reverts to static baseline" half of
  the dynamic rule below by construction.
- **Scope note, found while implementing**: `SERVICE_APPS` didn't exist
  as a `ServiceId` — the `AppsService` struct type was already defined in
  `services.h` but had no id to register under. Added it (`services.h`),
  since the plan's own static-tier table names "Apps" as a tiered
  service. Minimal addition, not a redesign — no `AppsService` instance
  is registered anywhere yet (the running app is still driven directly
  through the global `app_handler`, outside the services registry
  entirely); wiring that up is later-phase work, not part of this step.
- **Only `Time` and `Power` are actually registered anywhere right now**
  (`platform/pc/services_pc.c`; ESP32's `register_available_services` in
  `data_esp32.cpp` is still an empty stub) — so those are the only two
  services with `staticCriticality` set in code so far (`Time` = HIGH,
  `Power` = MED, matching the table). The rest of the table below is
  recorded as a doc comment directly above the enum in `services.h`, so
  whichever phase eventually registers `Input`/`Storage`/`Apps`/
  `Network`/`Bluetooth`/`Display`/`Notifications` has the intended tier
  already decided, not left to be re-litigated then.
- **Dynamic override rule — data model only, mechanism deferred.** The
  field exists and defaults to static baseline; the actual elevate-while-
  a-running-app-depends-on-it behavior needs Phase 6's app manifest
  `requires = {...}` field to know when to trigger, so there's nothing
  to wire up yet. Not a gap — this is the expected order per the plan.
- PC boot-and-smoke-test passed against this change (clean build, binary
  alive and responsive, no crash).
- **Static** tiers, assigned and reasoned:

  | Service | Tier | Reasoning |
  |---|---|---|
  | Time | HIGH | Core purpose of the device |
  | Input | HIGH | Without it, nothing is reachable at all |
  | Storage | MED | Apps/settings need it; core timekeeping doesn't |
  | Power | MED | Shutdown/sleep control is safety-relevant; battery-% is convenience — may split later |
  | Apps | MED | Real loss of function, but Time/Timer/Stopwatch are core OS now, not apps |
  | Network | LOW | Core watch function needs zero connectivity |
  | Bluetooth | LOW | Same reasoning, moot until built |
  | Display, Notifications | **Foundational — outside the tier scale** | Both are load-bearing for the failure-reporting mechanism itself |

- **Dynamic** override rule: a service's dynamic criticality is elevated
  above its static baseline only while a *currently running app's*
  manifest declares a dependency on it (see Phase 6), reverting to static
  baseline on app exit. No open-ended dynamic recalculation beyond this
  one explicit rule.

---

## Phase 3 — Serial shell

**Deliberately sequenced here, early** — not because it's simple, but
because it directly de-risks Phases 4 and 5 by giving live, on-demand
visibility into boot ordering and service-monitoring behavior while
they're being built, rather than relying solely on screen rendering or
scrolling serial log output.

- Minimal command shell over the existing USB-CDC serial connection first
  (`help`, `services` — dump the live registry with current criticality
  and availability, `log <level>` — adjust runtime verbosity, `reboot`).
- Architecture: reuse the existing `log.h` listener pattern — the shell is
  just another listener, plus a command-input side reading from `Serial`.
- WiFi transport deferred to a later pass once the serial version is
  proven — same command layer, different transport, not a rewrite.
- Headless-mode implication: once this exists, a unit with no display
  attached (or a `Display` failure) can still be fully operated and
  diagnosed through the shell — this is what allows Display's
  "foundational" status from Phase 2 to be *softened* later: the shell
  becomes a real fallback path for critical notifications when Display is
  down, not just a debug convenience.

---

## Phase 4 — Fault-tolerant boot & watchdog

- **Bounded-time init for every hardware service.** Current model handles
  a service *failing* cleanly; it doesn't yet handle one *hanging*
  (a genuine risk — I2C buses can lock up under fault conditions). Every
  `init()` gets an actual timeout, not just a pass/fail return.
- **Boot ordering — reconciled explicitly against already-proven physical
  constraints, not left to a naive criticality sort.** This project has
  two hard, non-negotiable ordering requirements discovered the hard way:
  MCP23017 must init before the display's `RST` pulse, and SD's SPI setup
  must run *after* the display's own SPI init or the board hangs. Rule:
  **respect known hard physical dependencies first; use static criticality
  only to order whatever's left** after those constraints are satisfied.
- **Watchdog timer** (already on the original project TODO, folded in here
  as the natural last line of defense for this whole phase).
- **Crash-surviving log sink.** New `log.h` listener that persists recent
  log lines to SD (falling back to NVS if SD is absent) before a
  watchdog-triggered reset. Nearly every hardware bug in this project's
  history was diagnosed by having a serial monitor live at the exact
  moment of a crash — this removes that dependency, giving real
  post-mortem debugging. The Phase 3 shell becomes the natural way to
  retrieve this log after reboot (a `crashlog` command).

---

## Phase 5 — Service monitoring loop

- Periodic re-registration / availability re-check for every service.
- Check frequency driven by **dynamic** criticality (per Phase 2) —
  scales down under low-battery conditions specifically for LOW-tier
  services (`Network`, `Bluetooth`), directly tying the criticality model
  to the project's stated power-efficiency goal.
- Criticality-significant availability changes fire a notification via
  `Notifications` (falling back to the Phase 3 shell if `Display`/
  `Notifications` themselves are down).

---

## Phase 6 — App capability declarations, SD hot-swap, Lua VM bounds

- **Manifest addition**: Lua app manifests gain a declared `requires =
  {...}` field (e.g. `{"Storage", "Network"}`).
- `app_handler` cross-checks a running app's declared requirements against
  live service availability (fed by Phase 5's monitoring loop).
- **SD hot-swap behavior**: card removed while an app that requires
  `Storage` (or another now-unavailable required service) is running →
  that app exits gracefully, a notification displays, the OS itself does
  not crash. An app with no such dependency, already loaded into RAM,
  continues running.
- **Lua VM bounds** — new, addressing a real gap in the current sandbox
  design: nothing currently stops a misbehaving script from hanging the
  synchronous per-frame update loop (`while true do end`) or growing
  unbounded memory. Add an instruction-count hook forcing a yield/timeout,
  and a memory ceiling per app VM. This belongs here specifically because
  it's the same `app_handler` boundary already being hardened for
  capability enforcement — one enforcement layer, not two.

---

## Phase 7 — Native settings system

- **Lookup hierarchy**: `SD → NVS → defaults`, structured to allow
  additional sources later without redesign.
- **Format**: `key=value`, versioned from the start (`version=1` field) —
  cheap now, allows detecting/migrating old files once the format ever
  changes, rather than silently misparsing them later.
- **Validation**: every known setting has a declared type and valid
  range/enum at its definition point; the parser rejects or falls back to
  default for anything outside that — never trusts a raw parsed value
  downstream. Directly a memory-safety/security audit target, since this
  parses untrusted external input by definition.
- **Write safety**: settings writes go to a `.tmp` file first, which
  replaces the real file only on successful completion, then is deleted —
  protects against a corrupt half-written file if power is cut mid-write
  (directly relevant given the project's own hardware power-isolation
  switch). Checksum-based validation deferred to a later pass, per your
  own scoping.
- **Storage location**: `.cyanos/` on SD (lowercase, matching the
  project's existing tree-naming convention).
- Deliberately independent of the Lua app-sandbox layer — settings do not
  share a base system with apps, since settings are more foundational.

---

## Phase 8 — Power-aware rendering

- Move off unconditional per-frame redraw toward event/dirty-flag-driven
  rendering.
- New event type for the one genuine exception: the watchface needs to
  visibly progress without external input. `EVENT_CLOCK_SECOND_TICK` (or
  an RTC-interrupt-driven equivalent) as the minimum-refresh escape hatch,
  detailed design deferred per earlier discussion.

---

## Phase 9 — Final audit

- Full pass against everything landed in Phases 1–8, closing the loop
  against the Phase 0 baseline.
- Explicit named targets, not just general review: memory safety across
  every new component (settings parser, shell command parser, Lua bounds
  enforcement), the debounce fix from Phase 0, and full ERC-equivalent
  logic review of the criticality/monitoring interaction.

---

## Footnoted, not blocking any phase

- **Unity-based unit tests** for the settings parser and service registry
  specifically — the two most pure-logic, security-relevant, hardware-free
  pieces in this whole plan. Folded in opportunistically as each is built,
  not scheduled as its own phase.

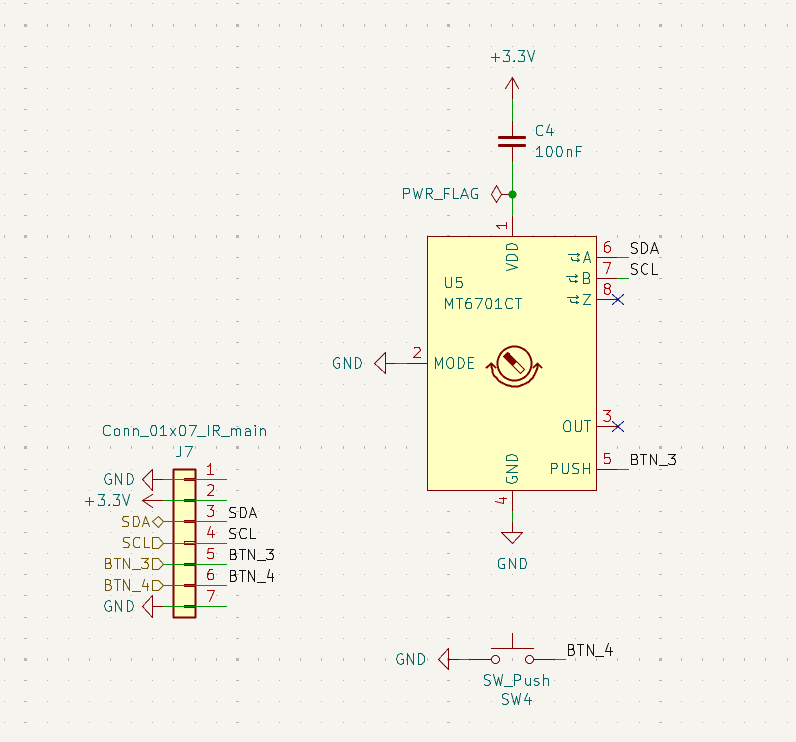
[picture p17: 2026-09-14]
docs/images/schematic-1.png

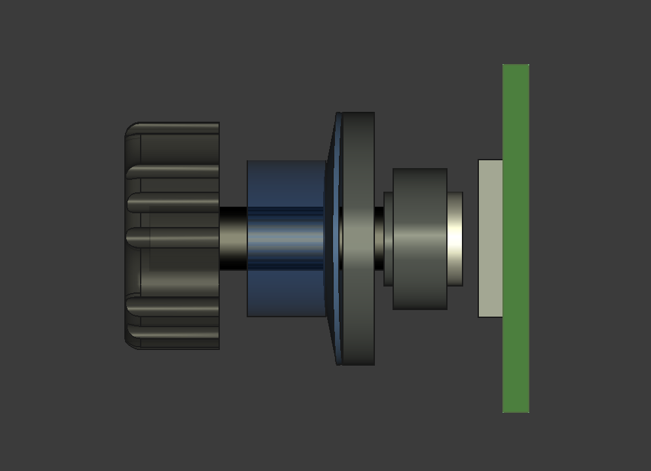
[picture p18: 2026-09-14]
docs/images/dial-design-1.png

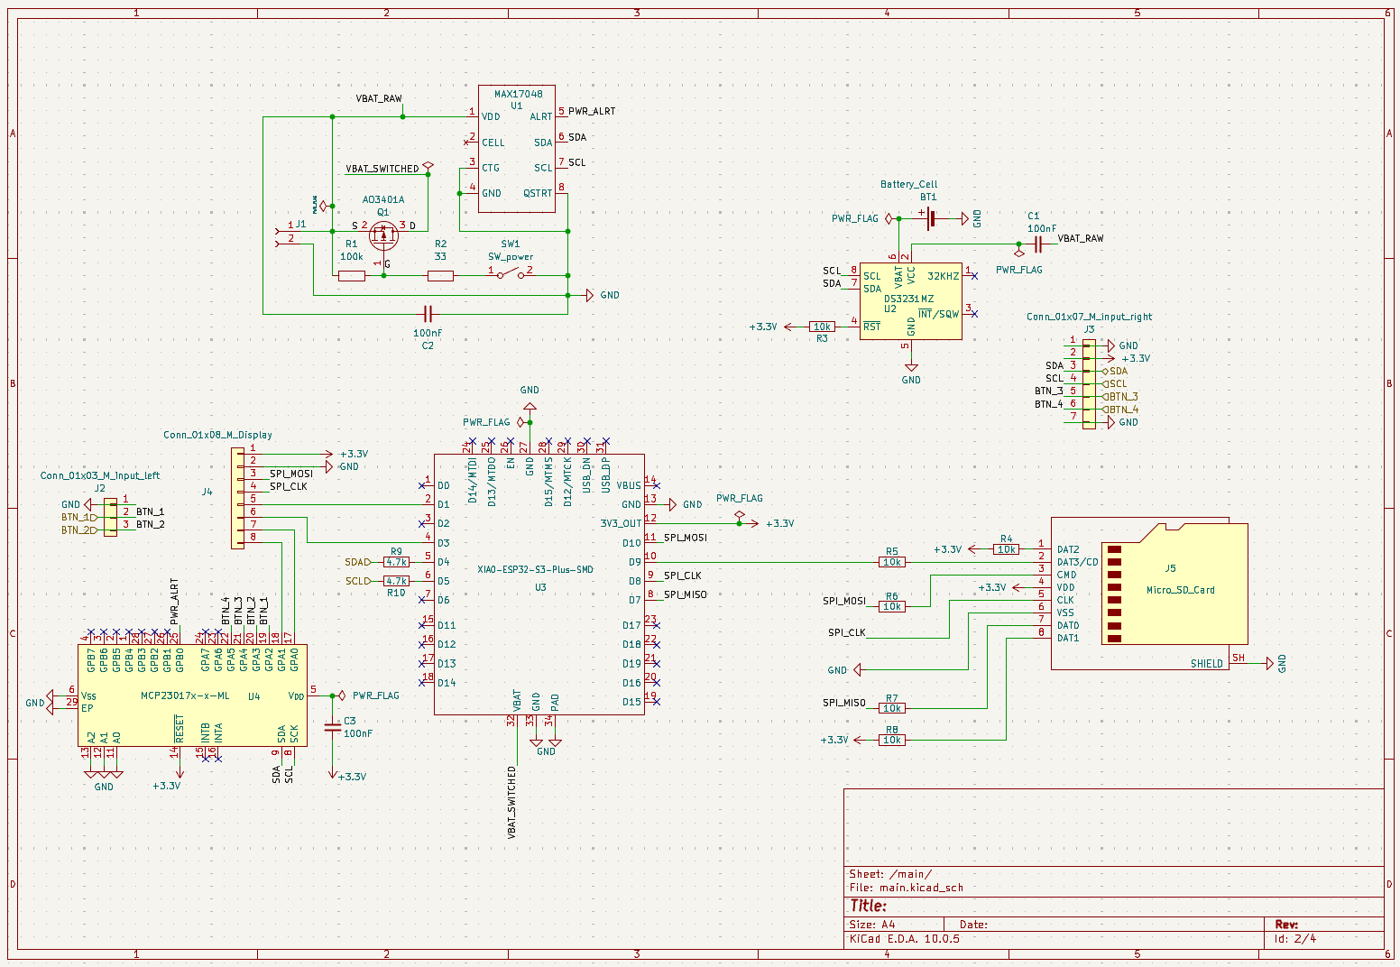
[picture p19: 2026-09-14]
docs/images/schematic-2.png

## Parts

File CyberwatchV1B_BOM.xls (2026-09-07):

PCBWay Bom Quotation, Product No.:T-3P2W1142579A
Item # | *Designator | *Qty | Manufacturer | *Mfg Part # | Description / Value | *Package/Footprint | Your Instructions / Notes | *Unit Price(3 units) | *Total | *Delivery Time | *Actual Purchase Mfg Part # | *PCBWay Note | Customer Reply | PCBWay Update
1 | BT1 | 1 | Keystone | 3000 | Battery_Cell | Battery:BatteryHolder_Keystone_3000_1x12mm |  | $0.589 | $1.767
2 | C1,C2,C3,C4 | 4 |  | CL10B104KB8NNNC | 100nF | Capacitor_SMD:C_0603_1608Metric |  | $0.067 | $0.804
3 | J1 | 1 |  | S2B-PH-SM4-TB(LF)(SN) | Conn_01x02_M_Battery | Connector_JST:JST_PH_S2B-PH-SM4-TB_1x02-1MP_P2.00mm_Horizontal |  | $0.488 | $1.464
4 | J2 | 1 |  | SM03B-SRSS-TB(LF)(SN) | Conn_01x03_M_input_left | Connector_JST:JST_SH_SM03B-SRSS-TB_1x03-1MP_P1.00mm_Horizontal |  | $0.419 | $1.257
5 | J3 | 1 |  | SM07B-SRSS-TB(LF)(SN) | Conn_01x07_M_input_right | Connector_JST:JST_SH_SM07B-SRSS-TB_1x07-1MP_P1.00mm_Horizontal |  | $0.650 | $1.950
6 | J4 | 1 |  | SM08B-GHS-TB(LF)(SN) | Conn_01x08_M_Display | Connector_JST:JST_GH_SM08B-GHS-TB_1x08-1MP_P1.25mm_Horizontal |  | $1.073 | $3.219
7 | J5 | 1 |  | 47219-2001 | Micro_SD_Card | Connector_Card:microSD_HC_Molex_47219-2001 | https://www.we-online.com/components/products/datasheet/693072010801.pdf | $0.939 | $2.817
8 | J6 | 1 |  | SM03B-SRSS-TB(LF)(SN) | Conn_01x03_IL_main | Connector_JST:JST_SH_SM03B-SRSS-TB_1x03-1MP_P1.00mm_Horizontal |  | $0.419 | $1.257
9 | J7 | 1 |  | SM07B-SRSS-TB(LF)(SN) | Conn_01x07_IR_main | Connector_JST:JST_SH_SM07B-SRSS-TB_1x07-1MP_P1.00mm_Horizontal |  | $0.650 | $1.950
10 | Q1 | 1 |  | AO3401A | AO3401A | Package_TO_SOT_SMD:SOT-23 | http://www.aosmd.com/pdfs/datasheet/AO3401A.pdf | $0.200 | $0.600 |  |  | brand:AOS
11 | R1 | 1 |  | RC0603FR-07100KL | 100k | Resistor_SMD:R_0603_1608Metric |  | $0.081 | $0.243
12 | R2 | 1 |  | RC0603FR-0733RL | 33 | Resistor_SMD:R_0603_1608Metric |  | $0.081 | $0.243
13 | R3,R4,R5,R6,R7,R8 | 6 |  | RC0603FR-0710KL | 10k | Resistor_SMD:R_0603_1608Metric |  | $0.025 | $0.450
14 | R9,R10 | 2 |  | RC0603FR-074K7L | 4.7k | Resistor_SMD:R_0603_1608Metric |  | $0.046 | $0.276
15 | SW1 | 1 |  | CHS-01A | SW_power | Button_Switch_SMD:SW_DIP_SPSTx01_Slide_Copal_CHS-01A_W5.08mm_P1.27mm_JPin |  | $2.298 | $6.894 | 7-10 Workdays
16 | SW2,SW3,SW4 | 3 |  | KMR231NG LFS | SW_Push | Button_Switch_SMD:SW_Push_1P1T_NO_CK_KMR2 |  | $1.305 | $11.745 | 7-10 Workdays
17 | U1 | 1 |  | MAX17048G+T10 | MAX17048 | Package_DFN_QFN:TDFN-8-1EP_2x2mm_P0.5mm_EP0.8x1.2mm | https://www.analog.com/media/en/technical-documentation/data-sheets/MAX17048-MAX17049.pdf | $2.683 | $8.049
18 | U2 | 1 |  | DS3231MZ+ | DS3231MZ | Package_SO:SOIC-8_3.9x4.9mm_P1.27mm | http://datasheets.maximintegrated.com/en/ds/DS3231M.pdf | $3.723 | $11.169
19 | U3 | 1 | SEEED | SEEED-113991114 | XIAO-ESP32-S3-Plus-SMD | Seeed_Studio_XIAO_Series:XIAO-ESP32-S3-Plus-SMD | https://www.mouser.co.uk/datasheet/3/1361/1/esp32_s3_datasheet.pdf | $11.707 | $35.121 | 7-10 Workdays | 113991114
20 | U4 | 1 |  | MCP23017-E/ML | MCP23017x-x-ML | Package_DFN_QFN:QFN-28-1EP_6x6mm_P0.65mm_EP4.25x4.25mm | https://ww1.microchip.com/downloads/aemDocuments/documents/APID/ProductDocuments/DataSheets/MCP23017-Data-Sheet-DS20001952.pdf | $2.818 | $8.454
21 | U5 | 1 |  | MT6701CT-STD | MT6701CT | Package_SO:SO-8_3.9x4.9mm_P1.27mm | https://www.scribd.com/document/932265028/MT6701-Rev-1-8 | $1.744 | $5.232
 |  |  |  |  |  |  |  | Component Cost | $104.96
 |  |  |  |  |  |  |  | Assembly Cost | $29.00
 |  |  |  |  |  |  |  | PCB Cost | $81.10
 |  |  |  |  |  |  |  | V0 Member 0% off | $0.00
 |  |  |  |  |  |  |  | All Total 3 Units | $215.06
 |  |  |  |  |  |  |  | delivery time | 24~27 days

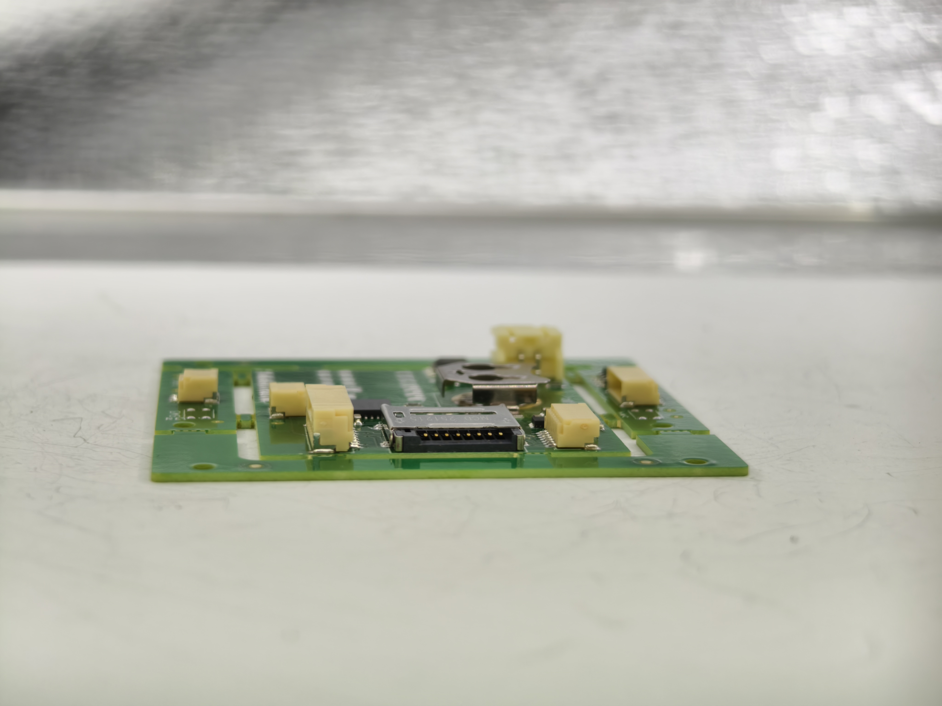
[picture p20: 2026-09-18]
docs/images/PCBWayOrderPhotos/T-3P2W1142579A (6).jpg

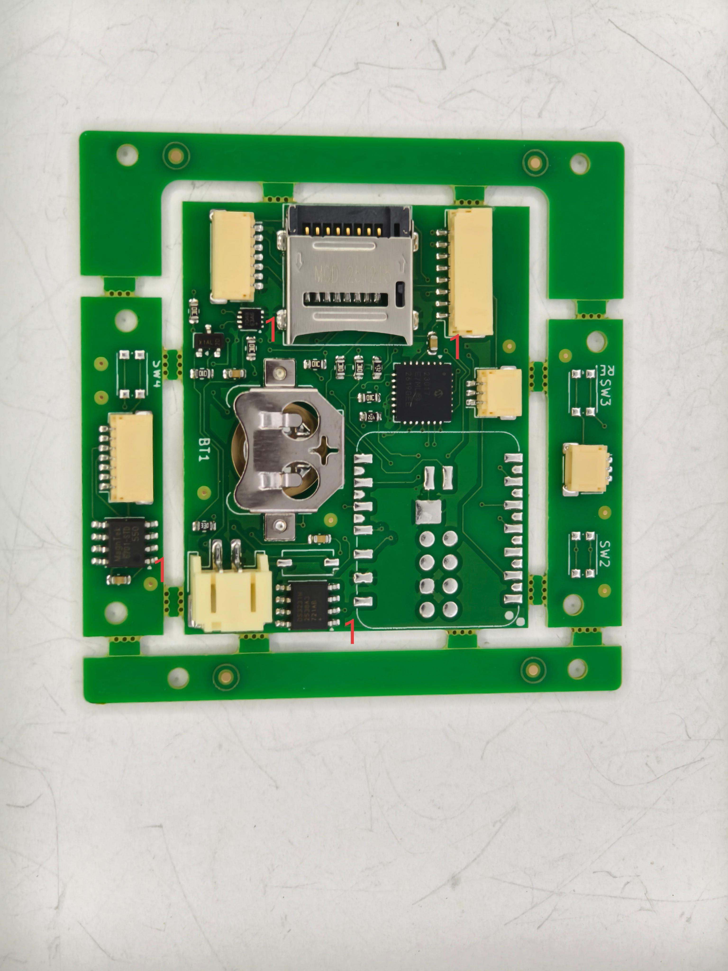
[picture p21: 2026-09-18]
docs/images/PCBWayOrderPhotos/T-3P2W1142579A (1).jpg

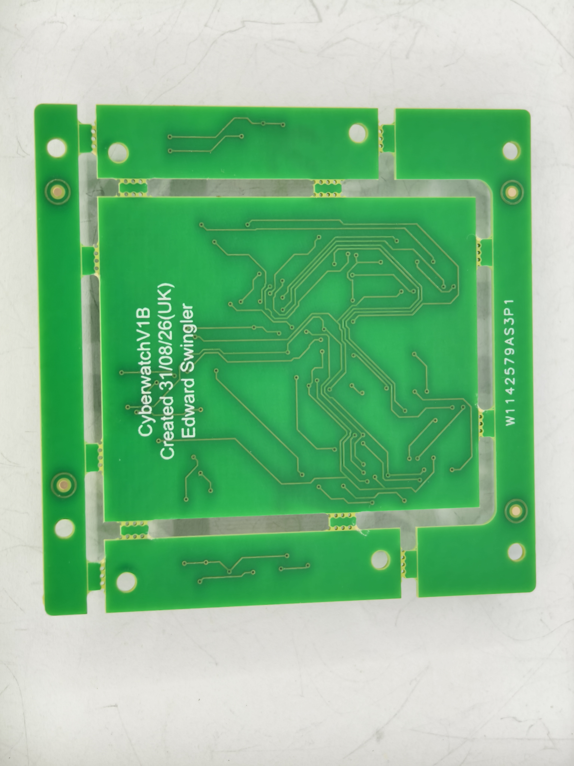
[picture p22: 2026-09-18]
docs/images/PCBWayOrderPhotos/T-3P2W1142579A (2).jpg

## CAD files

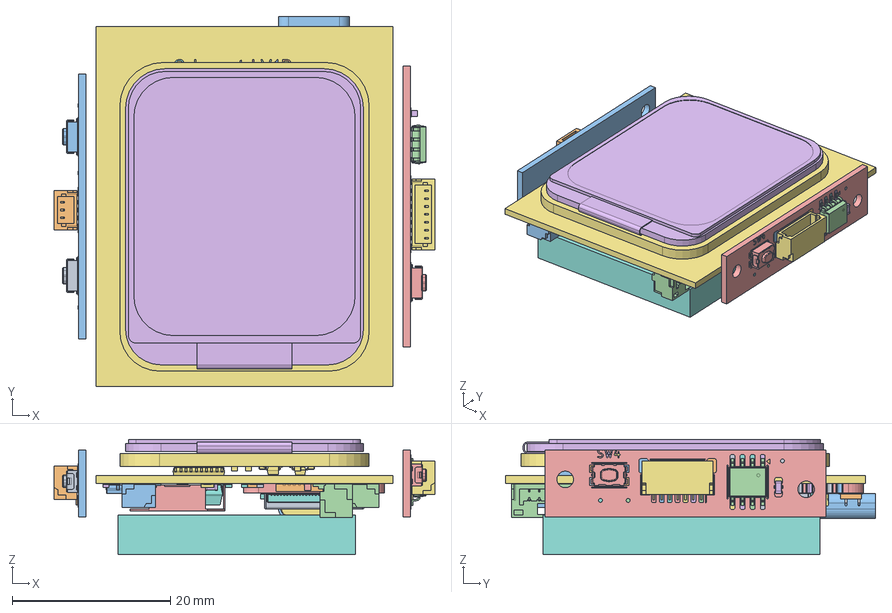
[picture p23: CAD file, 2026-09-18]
design/electronics/CyberwatchV1B/model/main.FCStd
48.1 x 46.8 x 14.6 mm
SW_Push_1P1T_NO_CK_KMR2
JST_SH_SM03B-SRSS-TB_1x03-1MP_P1.00mm_Horizontal
SW_Push_1P1T_NO_CK_KMR004
Cyb9916_pad003
Cyb9916_pad005
Cyb9916_pad006
Cyb9916_pad009
Cyb9916_pad012
Cyb9916_pad056
Cyb9916_pad057
Cyb9916_pad058
Cyb9916_pad061
Cyb9916_pad062
Cyb9916_pad063
Cyb9916_pad092
Cyb9916_pad093
Cyb9916_pad097
Cyb9916_pad105
Cyb9916_pad106
Cyb9916_silkscreen032
Cyb9916_silkscreen033
Cyb9916_silkscreen034
Cyb9916_silkscreen046
Cyb9916_silkscreen047
Cyb9916_silkscreen048
Cyb9916_silkscreen052
Cyb9916_silkscreen056
Cyb9916_silkscreen059
Cyb9916_silkscreen064
Cyb9916_silkscreen072
Cyb9916_silkscreen077
Cyb9916_silkscreen078
Cyb9916_silkscreen079
Cyb9916_silkscreen080
Cyb9916_silkscreen081
Cyb9916_silkscreen089
Cyb9916_silkscreen090
Cyb9916_silkscreen091
Cyb9916_silkscreen095
Cyb9916_silkscreen098
Cyb9916_silkscreen101
Cyb9916_silkscreen105
Cyb9916_PCB_3
SO-8_3.9x4.9mm_P1.27mm
SW_Push_1P1T_NO_CK_KMR006
C_0603_1608Metric006
JST_SH_SM07B-SRSS-TB_1x07-1MP_P1.00mm_Horizontal002
Cyb150C_pad
Cyb150C_pad010
Cyb150C_pad015
Cyb150C_pad016
Cyb150C_pad021
Cyb150C_pad027
Cyb150C_pad028
Cyb150C_pad033
Cyb150C_pad034
Cyb150C_pad037
Cyb150C_pad038
Cyb150C_pad039
Cyb150C_pad042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

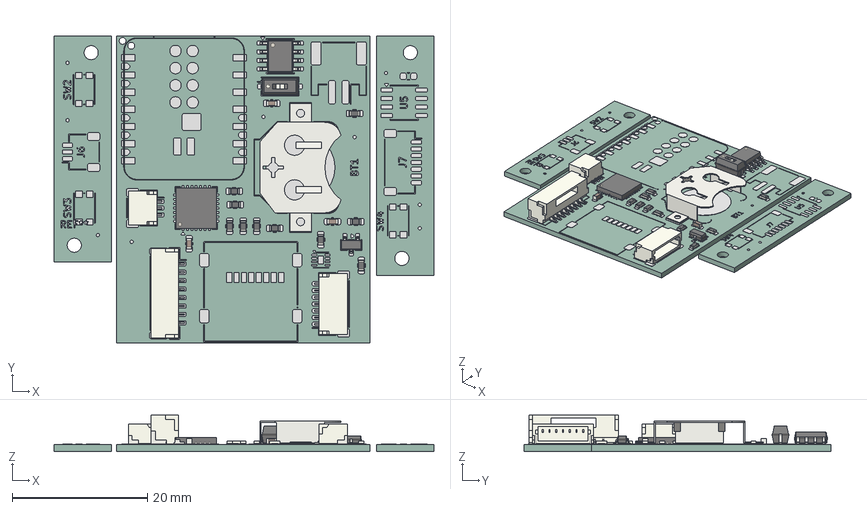
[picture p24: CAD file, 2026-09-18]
design/electronics/CyberwatchV1B/model/CyberwatchV1B-PCB-main.step
56.2 x 45.5 x 5.41 mm
R_0603_1608Metric x 10
C_0603_1608Metric x 3
Keystone_3000_1x12mm
SOT-23
JST_SM08B_GHS_TB
SOIC-8_3.9x4.9mm_P1.27mm
SW_DIP_SPSTx01_Slide_Copal_CHS_01A_W508mm_P127mm_JPin
QFN-28-1EP_6x6mm_Pitch0.65mm
JST_SH_SM07B-SRSS-TB_1x07-1MP_P1.00mm_Horizontal
JST_SH_SM03B-SRSS-TB_1x03-1MP_P1.00mm_Horizontal
Cyb2863_pad
Cyb2863_silkscreen x 2
Cyb2863_PCB_1
Cyb2863_PCB_2
Cyb2863_PCB_3

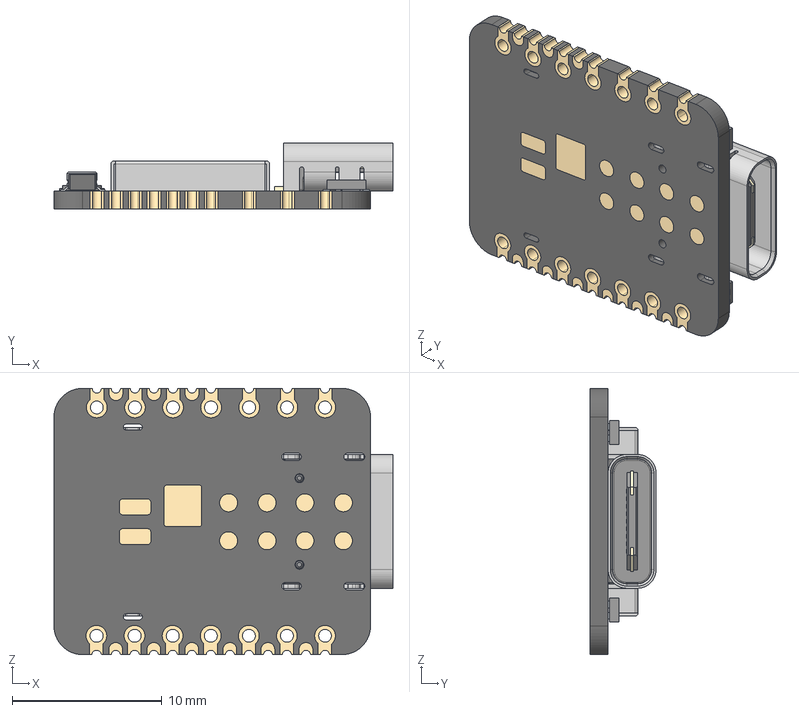
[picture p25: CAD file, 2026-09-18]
design/electronics/CyberwatchV1B/model/XIAO ESP32S3 PLUS_.step
22.6 x 4.42 x 17.8 mm
DF40C-30DP-0.4V_51_ v1
BOSS-EXTRUDE14_8_
BOSS-EXTRUDE7_4_
BOSS-EXTRUDE7_3_
BOSS-EXTRUDE14_4_
BOSS-EXTRUDE14_2_
BOSS-EXTRUDE14_11_
BOSS-EXTRUDE7_7_
BOSS-EXTRUDE14_9_
BOSS-EXTRUDE14_3_
BOSS-EXTRUDE14_7_
MIRROR2
BOSS-EXTRUDE14_5_
BOSS-EXTRUDE14_12_
BOSS-EXTRUDE7_8_
BOSS-EXTRUDE7_1_
BOSS-EXTRUDE14_10_
BOSS-EXTRUDE7_9_
BOSS-EXTRUDE14_6_
BOSS-EXTRUDE14_1_
BOSS-EXTRUDE7_6_
BOSS-EXTRUDE7_2_
CUT-EXTRUDE5
BOSS-EXTRUDE7_5_
Shield
Pins x 2
U.FL-R-SMT-1_10_ v1

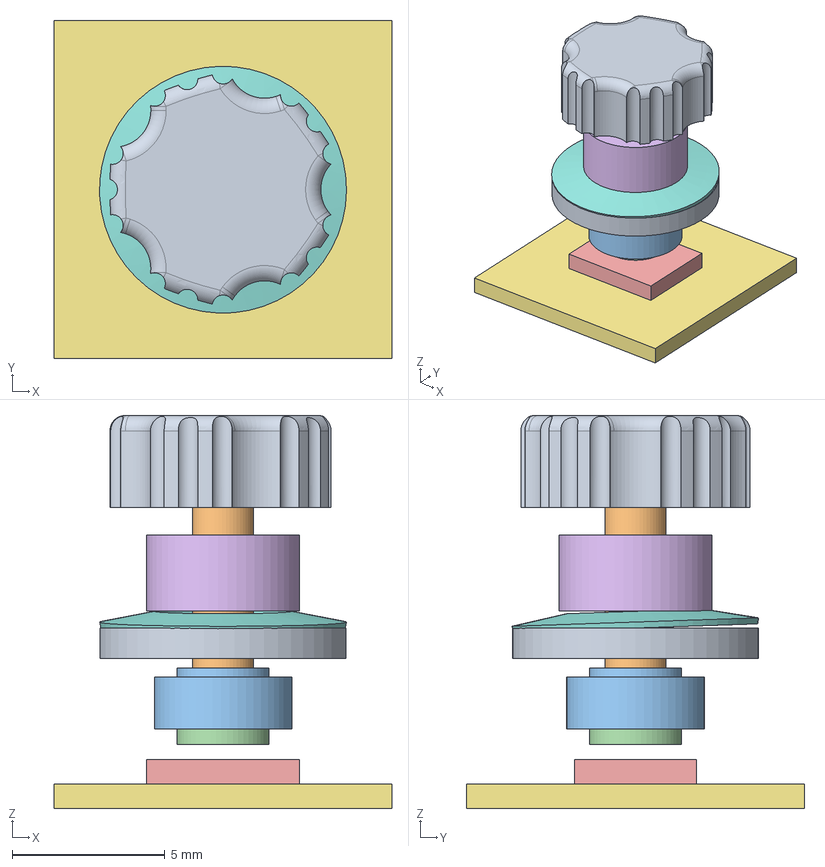
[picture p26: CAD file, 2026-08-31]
design/watch-crown/master4.FCStd
11.1 x 11.1 x 12.8 mm
CrownBody
PinBody
MagCarrierBody
MagnetRefBody
SensorRefBody
BearingRefBody
PcbRefBody
BellevilleRefBody
RetainerRefBody

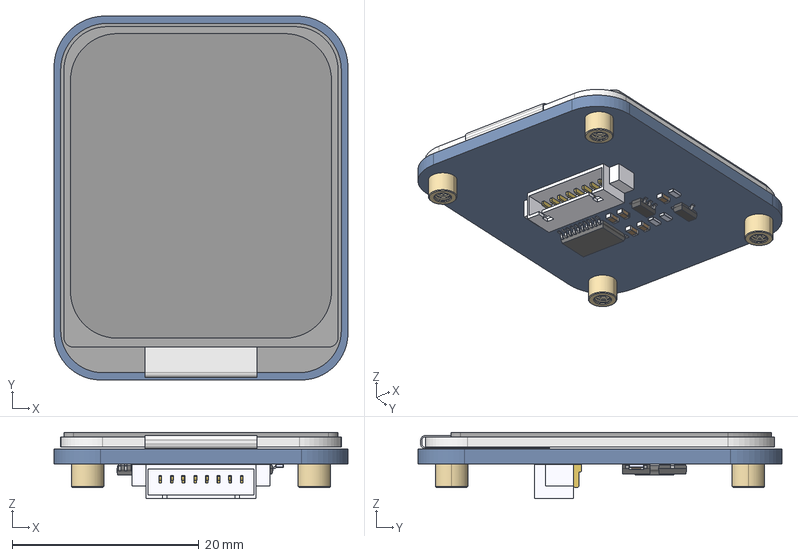
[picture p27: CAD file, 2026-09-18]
design/electronics/CyberwatchV1B/model/1_69inch-lcd-module.stp
31.5 x 39.0 x 7.11 mm
1_69INCH-240X280-LCD
1_69INCH_LCD_MODULE-PCBA
STUDS-M2XH2_5 x 4

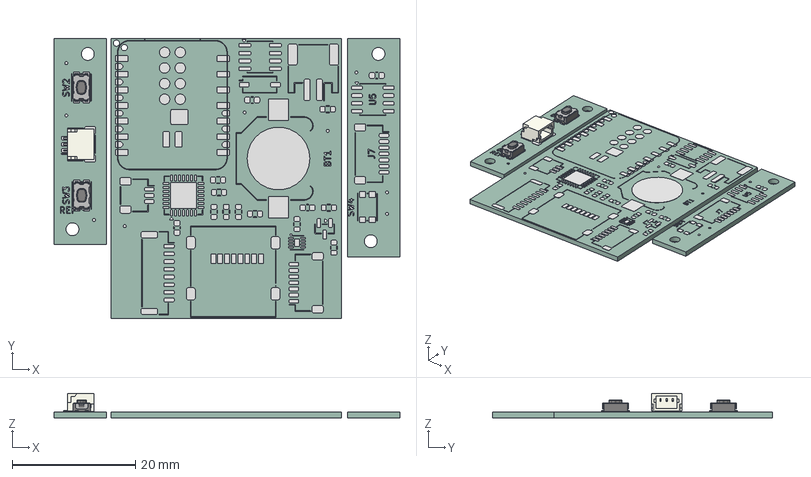
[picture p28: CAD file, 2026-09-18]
design/electronics/CyberwatchV1B/model/CyberwatchV1B-PCB-left.step
56.2 x 45.5 x 4.12 mm
SW_Push_1P1T_NO_CK_KMR2 x 2
JST_SH_SM03B-SRSS-TB_1x03-1MP_P1.00mm_Horizontal
Cyb9916_pad
Cyb9916_silkscreen x 2
Cyb9916_PCB_1
Cyb9916_PCB_2
Cyb9916_PCB_3

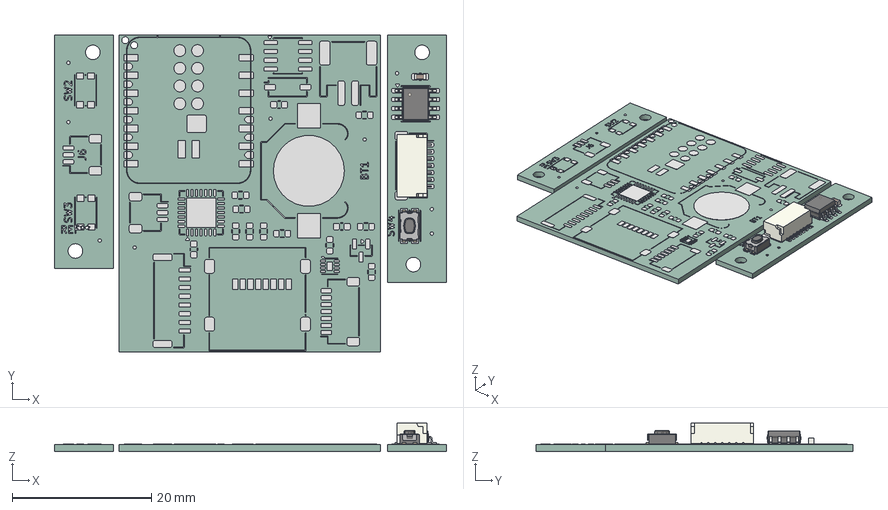
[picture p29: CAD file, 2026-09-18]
design/electronics/CyberwatchV1B/model/CyberwatchV1B-PCB-right.step
56.2 x 45.5 x 4.12 mm
SO-8_3.9x4.9mm_P1.27mm
SW_Push_1P1T_NO_CK_KMR2
C_0603_1608Metric
JST_SH_SM07B-SRSS-TB_1x07-1MP_P1.00mm_Horizontal
Cyb150C_pad
Cyb150C_silkscreen x 2
Cyb150C_PCB_1
Cyb150C_PCB_2
Cyb150C_PCB_3

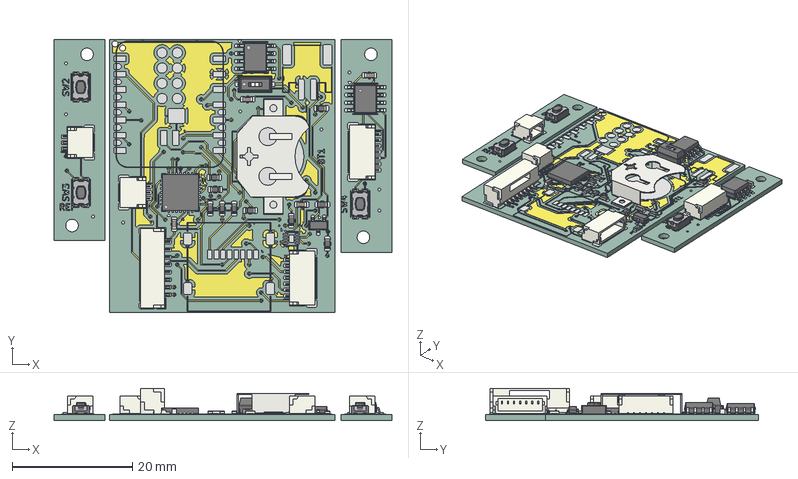
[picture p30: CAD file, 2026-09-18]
design/electronics/CyberwatchV1B/model/CyberwatchV1B-PCB-model.step
56.2 x 45.5 x 5.41 mm
R_0603_1608Metric x 10
C_0603_1608Metric x 4
Keystone_3000_1x12mm
SO-8_3.9x4.9mm_P1.27mm
SW_Push_1P1T_NO_CK_KMR2 x 3
SOT-23
JST_SH_SM03B-SRSS-TB_1x03-1MP_P1.00mm_Horizontal x 2
JST_SM08B_GHS_TB
SOIC-8_3.9x4.9mm_P1.27mm
JST_SH_SM07B-SRSS-TB_1x07-1MP_P1.00mm_Horizontal x 2
SW_DIP_SPSTx01_Slide_Copal_CHS_01A_W508mm_P127mm_JPin
QFN-28-1EP_6x6mm_Pitch0.65mm
Cyb714A_copper
Cyb714A_pad
Cyb714A_via
Cyb714A_silkscreen x 2
Cyb714A_PCB_1
Cyb714A_PCB_2
Cyb714A_PCB_3

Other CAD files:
design/case/case.FCStd

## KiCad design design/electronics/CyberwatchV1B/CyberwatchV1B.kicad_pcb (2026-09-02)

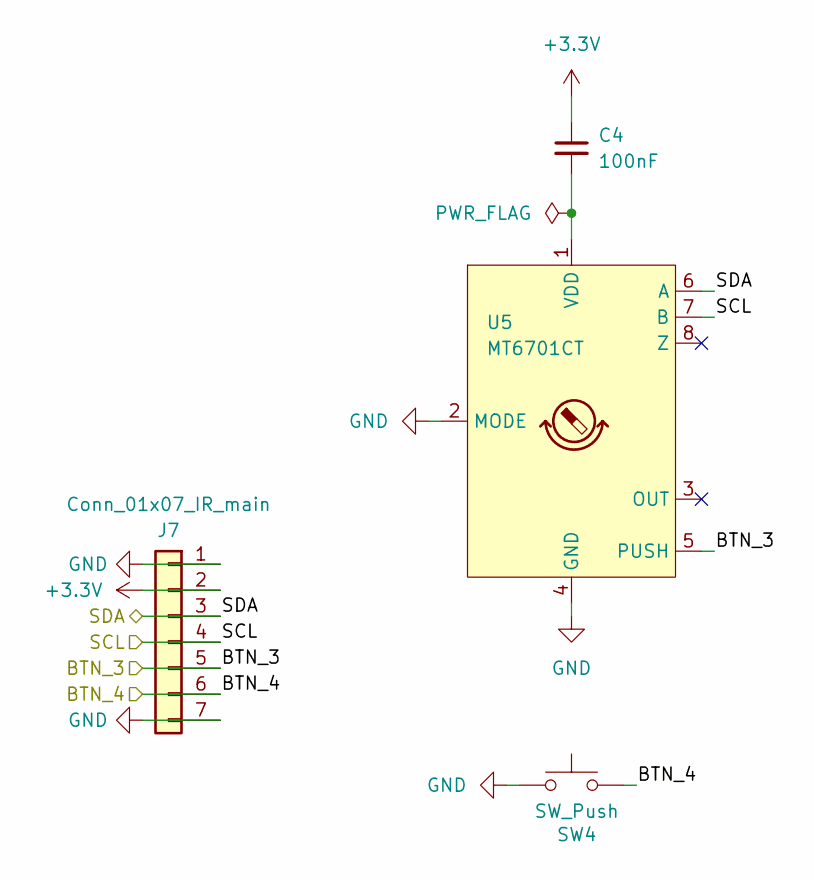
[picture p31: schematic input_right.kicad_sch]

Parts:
C4: 100nF; C_0603_1608Metric; MPN CL10B104KB8NNNC
J7: Conn_01x07_IR_main; JST_SH_SM07B-SRSS-TB_1x07-1MP_P1.00mm_Horizontal; MPN SM07B-SRSS-TB(LF)(SN)
SW4: SW_Push; SW_Push_1P1T_NO_CK_KMR2; MPN KMR231NG LFS
U5: MT6701CT; SO-8_3.9x4.9mm_P1.27mm; MPN MT6701CT-STD

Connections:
+3.3V: C4.1, J7.2; also elsewhere on the board
/input_right/BTN_3: J7.5, U5.5 (PUSH); also elsewhere on the board
/input_right/BTN_4: J7.6, SW4.2; also elsewhere on the board
/input_right/SCL: J7.4, U5.7 (B); also elsewhere on the board
/input_right/SDA: J7.3, U5.6 (A); also elsewhere on the board
GND: J7.1, J7.7, SW4.1, U5.2 (MODE), U5.4 (GND); also elsewhere on the board
unnamed: C4.2, U5.1 (VDD)

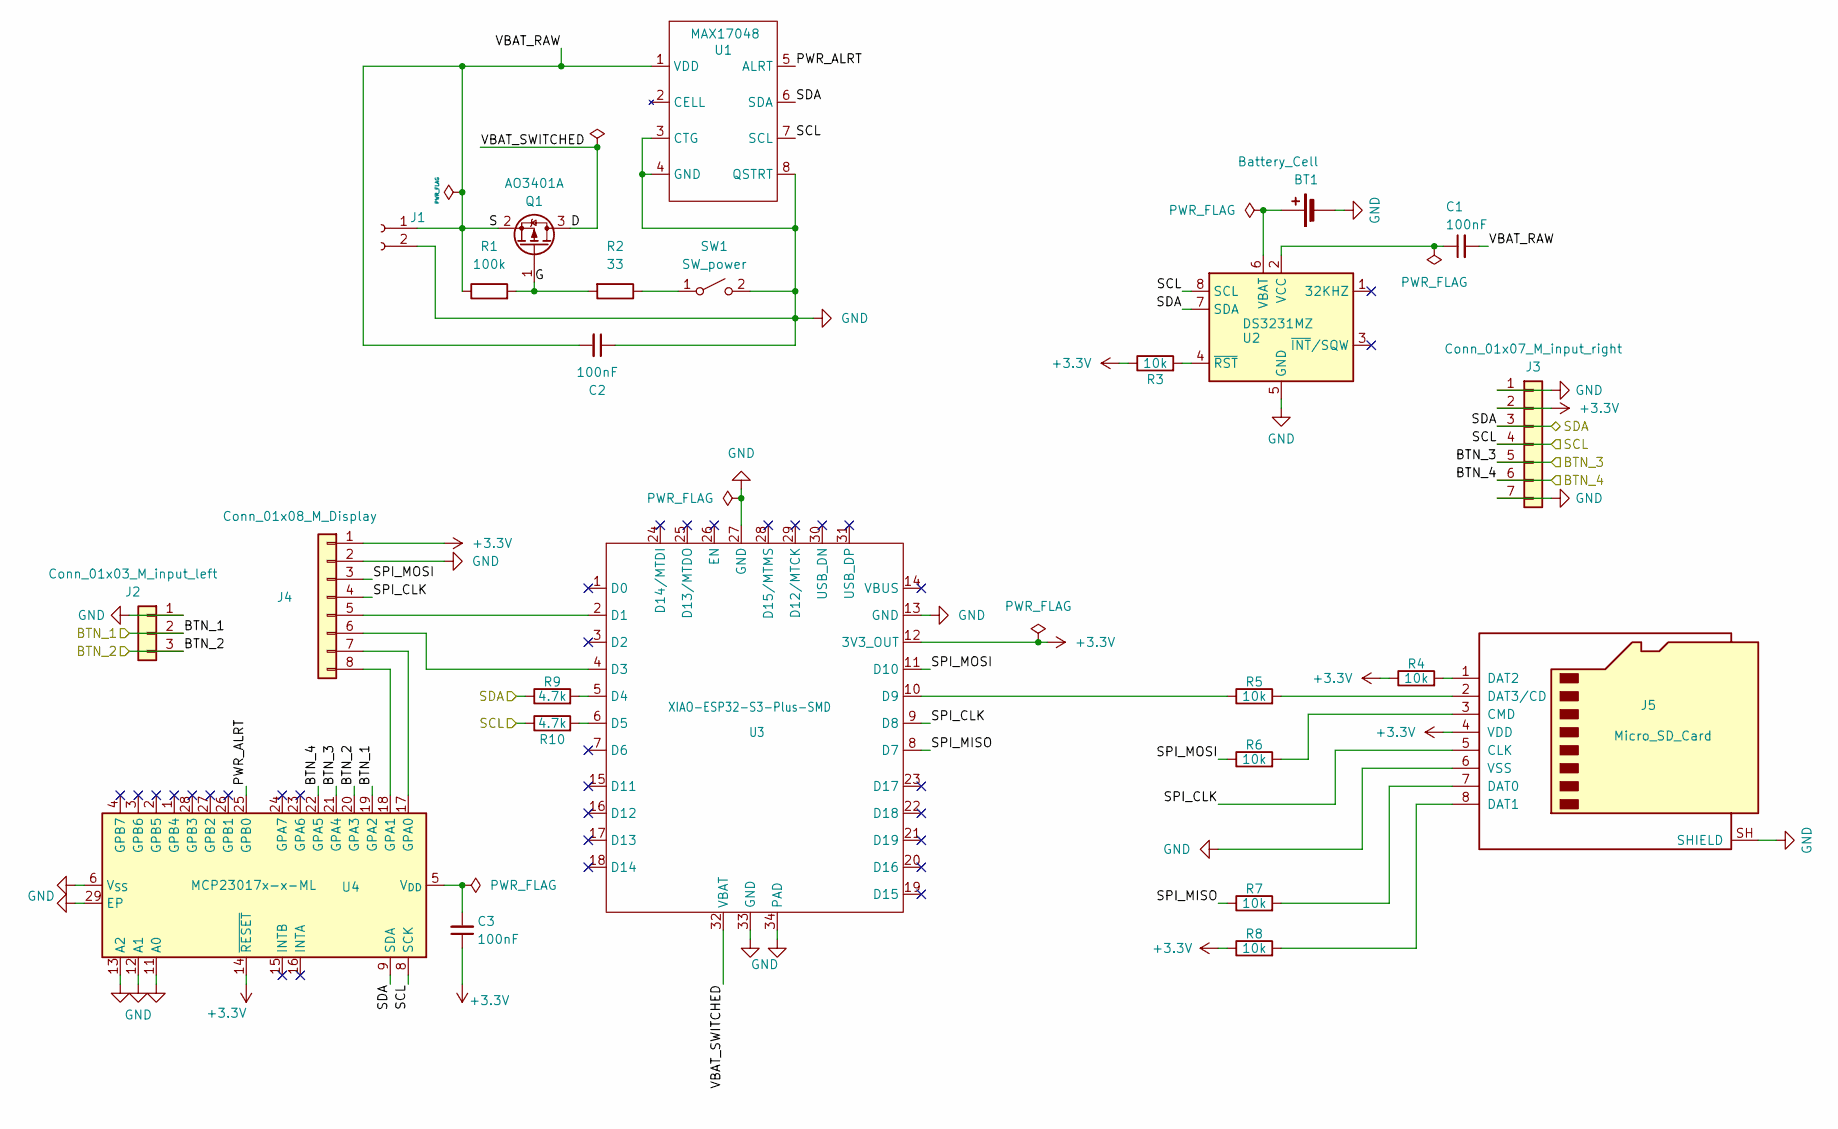
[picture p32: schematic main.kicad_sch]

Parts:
BT1: Battery_Cell; BatteryHolder_Keystone_3000_1x12mm; MPN Keystone 3000
C1, C2, C3: 100nF; C_0603_1608Metric; MPN CL10B104KB8NNNC
J1: Conn_01x02_M_Battery; JST_PH_S2B-PH-SM4-TB_1x02-1MP_P2.00mm_Horizontal; MPN S2B-PH-SM4-TB(LF)(SN)
J2: Conn_01x03_M_input_left; JST_SH_SM03B-SRSS-TB_1x03-1MP_P1.00mm_Horizontal; MPN SM03B-SRSS-TB(LF)(SN)
J3: Conn_01x07_M_input_right; JST_SH_SM07B-SRSS-TB_1x07-1MP_P1.00mm_Horizontal; MPN SM07B-SRSS-TB(LF)(SN)
J4: Conn_01x08_M_Display; JST_GH_SM08B-GHS-TB_1x08-1MP_P1.25mm_Horizontal; MPN SM08B-GHS-TB(LF)(SN)
J5: Micro_SD_Card; microSD_HC_Molex_47219-2001; MPN 47219-2001
Q1: AO3401A; SOT-23; MPN AO3401A
R1: 100k; R_0603_1608Metric; MPN RC0603FR-07100KL
R2: 33; R_0603_1608Metric; MPN RC0603FR-0733RL
R3, R4, R5, R6, R7, R8: 10k; R_0603_1608Metric; MPN RC0603FR-0710KL
R9, R10: 4.7k; R_0603_1608Metric; MPN RC0603FR-074K7L
SW1: SW_power; SW_DIP_SPSTx01_Slide_Copal_CHS-01A_W5.08mm_P1.27mm_JPin; MPN CHS-01A
U1: MAX17048; TDFN-8-1EP_2x2mm_P0.5mm_EP0.8x1.2mm; MPN MAX17048G+T10
U2: DS3231MZ; SOIC-8_3.9x4.9mm_P1.27mm; MPN DS3231MZ+
U3: XIAO-ESP32-S3-Plus-SMD
U4: MCP23017x-x-ML; QFN-28-1EP_6x6mm_P0.65mm_EP4.25x4.25mm; MPN MCP23017-E/ML

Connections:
+3.3V: C3.1, J3.2, J4.1 (VCC), J5.4 (VDD), R3.1, R4.1, R8.1, U3.12 (3V3_OUT), U4.14 (~RESET); also elsewhere on the board
/input_right/BTN_3: J3.5, U4.21 (GPA4); also elsewhere on the board
/input_right/BTN_4: J3.6, U4.22 (GPA5); also elsewhere on the board
/input_right/SCL: J3.4, R10.1, U1.7 (SCL), U2.8 (SCL), U4.8 (SCK); also elsewhere on the board
/input_right/SDA: J3.3, R9.1, U1.6 (SDA), U2.7 (SDA), U4.9 (SDA); also elsewhere on the board
/main/BTN_1: J2.2, U4.19 (GPA2); also elsewhere on the board
/main/BTN_2: J2.3, U4.20 (GPA3); also elsewhere on the board
/main/D: Q1.3 (D), U3.32 (VBAT)
/main/G: Q1.1 (G), R1.2, R2.2
/main/PWR_ALRT: U1.5 (ALRT), U4.25 (GPB0)
/main/S: C1.2, C2.2, J1.1, Q1.2 (S), R1.1, U1.1 (VDD)
/main/SPI_CLK: J4.4, J5.5 (CLK), U3.9 (D8)
/main/SPI_MISO: R7.1, U3.8 (D7)
/main/SPI_MOSI: J4.3 (DIN), R6.1, U3.11 (D10)
GND: BT1.2 (-), C2.1, J1.2, J2.1, J3.1, J3.7, J4.2 (GND), J5.6 (VSS), J5.SH (SHIELD), SW1.2 (B), U1.3 (CTG), U1.4 (GND), U1.8 (QSTRT), U2.5 (GND), U3.13 (GND), U3.27 (GND), U3.33 (GND), U3.34 (PAD), U4.6 (V_{SS}), U4.11 (A0), U4.12 (A1), U4.13 (A2), U4.29 (EP); also elsewhere on the board
unnamed: BT1.1 (+), U2.6 (VBAT)
unnamed: J4.5 (CS), U3.2 (D1)
unnamed: J4.6, U3.4 (D3)
unnamed: J4.7, U4.17 (GPA0)
unnamed: J4.8, U4.18 (GPA1)
unnamed: J5.3 (CMD), R6.2
unnamed: J5.7 (DAT0), R7.2
unnamed: J5.8 (DAT1), R8.2
unnamed: J5.1 (DAT2), R4.2
unnamed: J5.2 (DAT3/CD), R5.2
unnamed: R2.1, SW1.1 (A)
unnamed: C1.1, U2.2 (VCC)
unnamed: R3.2, U2.4 (~RST)
unnamed: R9.2, U3.5 (D4)
unnamed: R10.2, U3.6 (D5)
unnamed: R5.1, U3.10 (D9)
unnamed: C3.2, U4.5 (V_{DD})

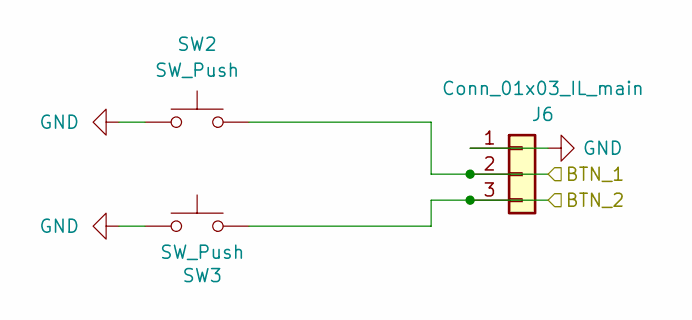
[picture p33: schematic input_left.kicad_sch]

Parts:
J6: Conn_01x03_IL_main; JST_SH_SM03B-SRSS-TB_1x03-1MP_P1.00mm_Horizontal; MPN SM03B-SRSS-TB(LF)(SN)
SW2, SW3: SW_Push; SW_Push_1P1T_NO_CK_KMR2; MPN KMR231NG LFS

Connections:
/main/BTN_1: J6.2, SW2.2; also elsewhere on the board
/main/BTN_2: J6.3, SW3.2; also elsewhere on the board
GND: J6.1, SW2.1, SW3.1; also elsewhere on the board

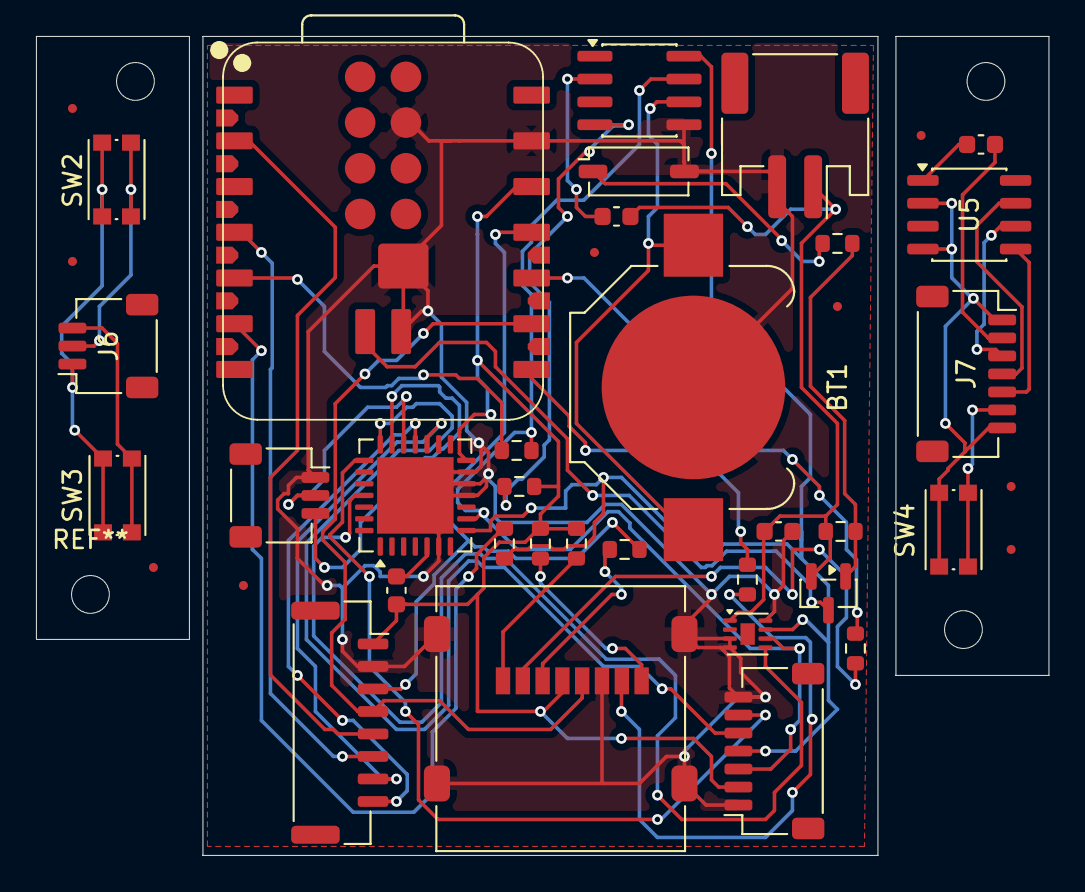
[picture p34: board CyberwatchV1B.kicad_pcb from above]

Board: 2 copper layers, 56.2 x 45.5 mm, 41 parts (0 on the bottom side), 33 nets.

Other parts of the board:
FID1, FID2, FID3, FID4, FID5, FID6, FID7, FID8, FID9: Fiducial_0.5mm_Mask1.5mm

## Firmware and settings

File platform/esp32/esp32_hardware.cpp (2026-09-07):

// esp32_hardware.cpp
#include "esp32_hardware.h"
#include "../../cyan/console/log.h"
#include "secrets.h"
#include <Arduino.h>
#include <SD.h>
#include <SPI.h>
#include <Wire.h>

Adafruit_MCP23X17 mcp;
bool mcpReady = false;
bool sdReady = false;

#define PIN_SD_SCK D8   // shared with display
#define PIN_SD_MOSI D10 // shared with display
#define PIN_SD_MISO D7
#define PIN_SD_CS D9

static void scan_i2c() {
    cyan_log(VERBOSE_LOW, "[Hardware/I2C] Scanning...");
    int found = 0;
    for (byte address = 1; address < 127; address++) {
        Wire.beginTransmission(address);
        byte error = Wire.endTransmission();
        if (error == 0) {
            cyan_log(VERBOSE_HIGH, ">    Found device: 0x%02X", address);
            found++;
        }
    }
    cyan_log(VERBOSE_LOW, "[Hardware/I2C] OK: %d device(s) found.", found);
}

static void connect_wifi() {
    cyan_log(VERBOSE_LOW, "[Services/WiFi] Scanning...");
    int n = WiFi.scanNetworks();
    cyan_log(VERBOSE_LOW, "[Services/WiFi] OK: %d network(s) found.", n);
    for (int i = 0; i < n; i++) {
        cyan_log(
            VERBOSE_HIGH, ">    %s (RSSI %d dBm, ch %d, %s)", WiFi.SSID(i).c_str(), WiFi.RSSI(i),
            WiFi.channel(i), WiFi.encryptionType(i) == WIFI_AUTH_OPEN ? "open" : "secured"
        );
    }

    WiFi.mode(WIFI_STA);
    WiFi.begin(ssid, password);

    cyan_log(VERBOSE_LOW, "[Services/WiFi] Connecting...");
    uint32_t start = millis();
    while (WiFi.status() != WL_CONNECTED && millis() - start < 20000) {
        delay(500);
    }

    if (WiFi.status() == WL_CONNECTED) {
        cyan_log(VERBOSE_LOW, "[Services/WiFi] OK: connected.");
        cyan_log(VERBOSE_LOW, ">    IP: %s", WiFi.localIP().toString().c_str());
        cyan_log(VERBOSE_LOW, ">    Gateway: %s", WiFi.gatewayIP().toString().c_str());
        cyan_log(VERBOSE_LOW, ">    RSSI: %d dBm", WiFi.RSSI());
    } else {
        cyan_log(VERBOSE_LOW, "[Services/WiFi] FAILED: status %d.", WiFi.status());
    }
}

bool esp32_hardware_init(void) {
    Wire.begin(D4, D5);
    scan_i2c();
    connect_wifi();
    mcpReady = mcp.begin_I2C();
    if (!mcpReady) {
        cyan_log(VERBOSE_LOW, "[Hardware/MCP23017] FAILED: device not found.");
        return false;
    }
    cyan_log(VERBOSE_LOW, "[Hardware/MCP23017] OK.");

    mcp.pinMode(MCP_BTN1, INPUT_PULLUP);
    mcp.pinMode(MCP_BTN2, INPUT_PULLUP);
    mcp.pinMode(MCP_DISP_RST, OUTPUT);
    mcp.pinMode(MCP_DISP_BL, OUTPUT);
    mcp.pinMode(MCP_DIAL_SW, INPUT_PULLUP);

    return true;
}

// must run AFTER the display's own Arduino_ESP32SPI has configured the shared bus, called from
// display_init() Calling this before display init caused hang
bool esp32_sd_init(void) {
    SPI.begin(PIN_SD_SCK, PIN_SD_MISO, PIN_SD_MOSI, PIN_SD_CS);
    sdReady = SD.begin(PIN_SD_CS, SPI, 400000);
    if (sdReady) {
        cyan_log(VERBOSE_LOW, "[Hardware/SDCard] OK: %llu MB.", SD.cardSize() / (1024 * 1024));
    } else {
        cyan_log(VERBOSE_LOW, "[Hardware/SDCard] FAILED: card not found.");
    }
    return sdReady;
}

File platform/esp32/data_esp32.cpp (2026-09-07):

// data_esp32.cpp
#include "esp32_hardware.h"
#include <Arduino.h>
#include <RTClib.h>
#include <SD.h>
#include <stdlib.h>
#include <string.h>

extern "C" {
#include "../../cyan/data/data.h"
}

#define ENCODER_CLK_PIN D0
#define ENCODER_DT_PIN D2

static RTC_DS3231 rtc;
static bool rtcReady = false;
static bool lastButton1Pressed = false;
static bool lastButton2Pressed = false;
static bool lastDialPressed = false;

static int encoderDelta = 0;
static uint8_t lastEncoded = 0;
static bool encoderInitialized = false;

void IRAM_ATTR encoder_isr() {
    uint8_t msb = digitalRead(ENCODER_CLK_PIN);
    uint8_t lsb = digitalRead(ENCODER_DT_PIN);
    uint8_t encoded = (msb << 1) | lsb;
    uint8_t sum = (lastEncoded << 2) | encoded;
    if (sum == 0b1101 || sum == 0b0100 || sum == 0b0010 || sum == 0b1011)
        encoderDelta++;
    else if (sum == 0b1110 || sum == 0b0111 || sum == 0b0001 || sum == 0b1000)
        encoderDelta--;
    lastEncoded = encoded;
}

static void append_event(CyanData* data, EventType type) {
    if (data->eventQueue.len + 1 < MAX_EVENTS) {
        data->eventQueue.events[data->eventQueue.len].type = type;
        data->eventQueue.len += 1;
    }
}

static void poll_buttons(CyanData* data) {
    if (!mcpReady)
        return;

    bool pressed1 = !mcp.digitalRead(MCP_BTN1);
    if (pressed1 != lastButton1Pressed) {
        append_event(data, pressed1 ? EVENT_BUTTON1_DOWN : EVENT_BUTTON1_UP);
        lastButton1Pressed = pressed1;
    }

    bool pressed2 = !mcp.digitalRead(MCP_BTN2);
    if (pressed2 != lastButton2Pressed) {
        append_event(data, pressed2 ? EVENT_BUTTON2_DOWN : EVENT_BUTTON2_UP);
        lastButton2Pressed = pressed2;
    }

    bool pressedDial = !mcp.digitalRead(MCP_DIAL_SW);
    if (pressedDial != lastDialPressed) {
        append_event(data, pressedDial ? EVENT_BUTTON3_DOWN : EVENT_BUTTON3_UP);
        lastDialPressed = pressedDial;
    }
}

static void poll_encoder(CyanData* data) {
    if (!encoderInitialized) {
        pinMode(ENCODER_CLK_PIN, INPUT_PULLUP);
        pinMode(ENCODER_DT_PIN, INPUT_PULLUP);
        attachInterrupt(digitalPinToInterrupt(ENCODER_CLK_PIN), encoder_isr, CHANGE);
        attachInterrupt(digitalPinToInterrupt(ENCODER_DT_PIN), encoder_isr, CHANGE);
        encoderInitialized = true;
    }

    noInterrupts();
    int delta = encoderDelta;
    encoderDelta = 0;
    interrupts();

    static int accumulated = 0;
    accumulated += delta;
    while (accumulated >= 4) {
        append_event(data, EVENT_SCROLL_UP);
        accumulated -= 4;
    }
    while (accumulated <= -4) {
        append_event(data, EVENT_SCROLL_DOWN);
        accumulated += 4;
    }
}

static void read_rtc(CyanData* data) {
    if (!rtcReady)
        return;
    DateTime now = rtc.now();
    data->watchface.time.tm_sec = now.second();
    data->watchface.time.tm_min = now.minute();
    data->watchface.time.tm_hour = now.hour();
    data->watchface.time.tm_mday = now.day();
    data->watchface.time.tm_mon = now.month() - 1;
    data->watchface.time.tm_year = now.year() - 1900;
    data->watchface.time.tm_wday = now.dayOfTheWeek();
}

float get_delta(void) {
    static unsigned long lastMillis = 0;
    unsigned long now = millis();
    float delta = (lastMillis == 0) ? 0.0f : (float)(now - lastMillis) / 1000.0f;
    lastMillis = now;
    return delta;
}

void update_data(CyanData* data, Display* display, bool* running) {
    (void)display;
    *running = true;
    data->eventQueue.len = 0;

    if (!rtcReady) {
        rtcReady = rtc.begin();
        if (rtcReady)
            cyan_log(VERBOSE_HIGH, "[Hardware] RTC OK");
    }

    poll_buttons(data);
    poll_encoder(data);
    read_rtc(data);
}

bool has_event_type(EventQueue* queue, EventType type) {
    for (int i = 0; i < queue->len; i++) {
        if (queue->events[i].type == type) {
            return true;
        }
    }
    return false;
}

static const char* base_name(const char* path) {
    const char* lastSlash = strrchr(path, '/');
    return lastSlash ? lastSlash + 1 : path;
}

static void resolve_sd_api_path(const char* relativePath, char* outBuffer, size_t bufferSize) {
    if (relativePath[0] == '/') {
        snprintf(outBuffer, bufferSize, "%s", relativePath);
    } else {
        snprintf(outBuffer, bufferSize, "/%s", relativePath);
    }
}

void platform_store_resolved_path(const char* relativePath, char* outBuffer, size_t bufferSize) {
    if (relativePath[0] == '/') {
        snprintf(outBuffer, bufferSize, "/sd%s", relativePath);
    } else {
        snprintf(outBuffer, bufferSize, "/sd/%s", relativePath);
    }
}

FolderList scan_folder(char* path) {
    FolderList result = {0};
    if (!sdReady) {
        cyan_log(VERBOSE_HIGH, "[Services/Memory] scan_folder: SD not ready");
        return result;
    }

    char resolvedPath[256];
    resolve_sd_api_path(path, resolvedPath, sizeof(resolvedPath));

    File dir = SD.open(resolvedPath);
    if (!dir || !dir.isDirectory()) {
        cyan_log(VERBOSE_HIGH, "[Services/Memory] scan_folder: could not open '%s'", resolvedPath);
        return result;
    }

    File entry;
    while ((entry = dir.openNextFile()) && result.count < MAX_FOLDERS) {
        if (entry.isDirectory()) {
            const char* name = base_name(entry.name());
            if (strcmp(name, ".") != 0 && strcmp(name, "..") != 0) {
                snprintf(result.names[result.count], MAX_FILE_NAME, "%s", name);
                result.count++;
            }
        }
        entry.close();
    }
    dir.close();
    return result;
}

#pragma pack(push, 1)
struct BmpHeader {
    uint16_t signature;
    uint32_t fileSize;
    uint32_t reserved;
    uint32_t dataOffset;
    uint32_t headerSize;
    int32_t width;
    int32_t height;
    uint16_t planes;
    uint16_t bitsPerPixel;
    uint32_t compression;
};
#pragma pack(pop)
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

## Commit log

2026-07-27 battery icon fix
2026-07-28 half broken up clay_ui.c and added tab switching
2026-07-28 fixed app switching adding timer
2026-07-29 tab switching, stopwatch added
2026-07-30 beginning esp32s3-plus port
2026-08-02 ESP32-S3-PLUS bringup
2026-08-06 standardised icons, started PCB design
    [CyberwatchV1B.kicad_pcb, CyberwatchV1B.kicad_sch]
2026-08-10 design progress
    [CyberwatchV1B.kicad_pcb, CyberwatchV1B.kicad_sch, crown.FCStd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]
2026-08-10 crown design progress
    [master.FCStd]
2026-08-10 design tweak
    [master.FCStd]
2026-08-16 Phase 1: rename CyberwatchData -> CyanData
    Isolated rename sweep, deferred from Phase 0 per the integrity plan.
    Touches every file with a `data->` access (16 files) plus the
    cyan_os.h include guard (CYBERWATCH_H -> CYAN_OS_H), which was leftover
    from the same pre-rename name. Also reconciles the integrity plan doc
    with the phase0-pc-verified-2 checkpoint and the explicit decision to
    proceed into Phase 1 without ESP32 hardware access for now.
2026-08-18 minor AppHandler refactor + electronics update
    [CyberwatchV1B.kicad_pcb, CyberwatchV1B.kicad_sch, crown.FCStd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]
2026-08-21 power schematic progres
    [CyberwatchV1B.kicad_sch, input_left.kicad_sch, input_right.kicad_sch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]
2026-08-22 power update confirm
    [power.kicad_sch]
2026-08-22 power schematic finalisation
    [CyberwatchV1B.kicad_sch, main.kicad_sch, power.kicad_sch]
2026-08-22 documentation and electronics main board progress
    [CyberwatchV1B.kicad_sch, main.kicad_sch]
2026-08-23 electronics progres
    [CyberwatchV1B.kicad_pcb, CyberwatchV1B.kicad_sch, input_left.kicad_sch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]
2026-08-24 schematic complete
    [CyberwatchV1B.kicad_sch, input_left.kicad_sch, input_right.kicad_sch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]
2026-08-29 Phase 1: finish naming sweep, revert AppHandler_ drift, remove dead code
    Reconciles 8 commits' worth of gap in the integrity plan doc since the
    last status update at 6d60554. c793bb0 had silently renamed every
    app_handler_* function to AppHandler_* (PascalCase), undocumented,
    breaking from the snake_case convention every other module still
    follows -- reverted per explicit decision. Also finishes Phase 1's two
    outstanding dead-code items: the vestigial empty timer_handling.c and
    the unused display_load_image() in display_st7789.cpp.
    PC boot-and-smoke-test passed: clean build, binary stayed alive and
    responsive, no crash.
    [display_st7789.cpp]
2026-08-29 Phase 2: criticality model data layer
    Adds the CyanCriticality enum (LOW/MED/HIGH/FOUNDATIONAL) and the
    staticCriticality/dynamicCriticality fields on Service, per the
    integrity plan. services_register() seeds dynamicCriticality to the
    static baseline at registration time. Added SERVICE_APPS to ServiceId
    since the plan's tier table names Apps but no id existed for it yet
    (AppsService the struct type already existed, unregistered).
    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
2026-08-29 Audit: remove dead platform_resolve_path, log services-registry gap
    platform_resolve_path() was declared in data.h and defined on both
    platforms (SDL_malloc- and malloc-backed respectively) with zero call
    sites anywhere -- distinct from platform_store_resolved_path(), which
    is the caller-buffer variant actually in use everywhere. Removed from
    data.h, data_pc.c, data_esp32.cpp.
    Also logs a real architectural finding found while reading data_esp32.cpp
    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
2026-08-31 pcb design
    [CyberwatchV1B.kicad_pcb, CyberwatchV1B.kicad_sch, input_left.kicad_sch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]
2026-08-31 pcb design 2
    [CyberwatchV1B.kicad_pcb, CyberwatchV1B_BOM.csv]
2026-08-31 PCB design finalisation
    [CyberwatchV1B.kicad_pcb, CyberwatchV1B_BOM.csv, input_left.kicad_sch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]
2026-09-01 pcb fabrication prep
    [CyberwatchV1B-B_Adhesive.gbr, CyberwatchV1B-B_Courtyard.gbr, CyberwatchV1B-B_Cu.gbr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]
2026-09-02 pcb fabrication adjustment: no via in pads
    [CyberwatchV1B-B_Adhesive.gbr, CyberwatchV1B-B_Courtyard.gbr, CyberwatchV1B-B_Cu.gbr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]
2026-09-07 settings started
    [CyberwatchV1B_BOM.xls, CyberwatchV1B_BOM2.xls]
2026-09-11 added interpretting settings values
    [input_right.kicad_sch, main.kicad_sch]
2026-09-15 small update
    [CyberwatchV1B-all-pos.csv]
